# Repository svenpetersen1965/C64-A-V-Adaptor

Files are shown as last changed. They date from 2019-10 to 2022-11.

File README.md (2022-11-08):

# C64-A-V-Adaptor
An A/V-adaptor board for the C64
This board is intended to connect to the Commodore C64 and use standard cables (audio, composite with RCA connector and/or s-video with a mini-DIN cable).

It also provides a 330Ohm resistor, which attenuates the s-video chroma line. This resistor can be bridged with a jumper. 

Also an optional stereo output on pin 7 of the a/v jack (stereo sid, FPGA SID etc.) can be connected to the right audio channel. By default, this channel is also connected to the (mono) audio output.

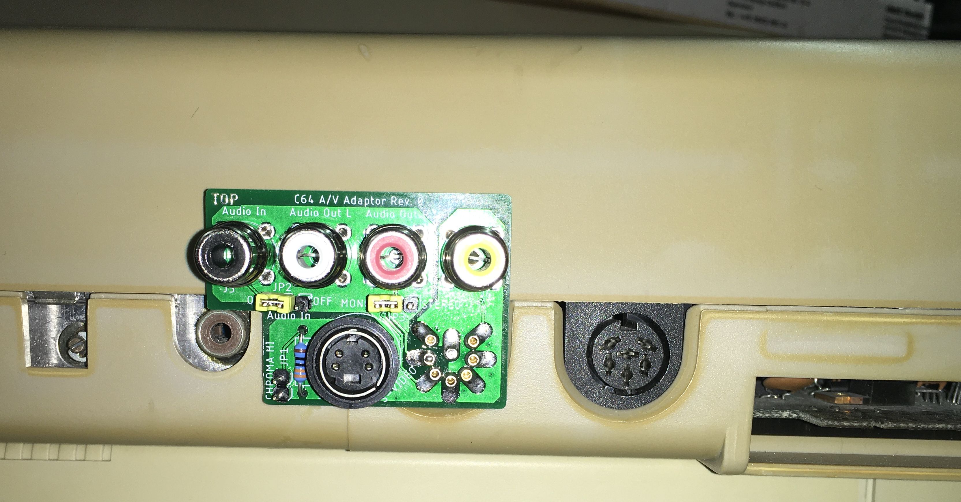
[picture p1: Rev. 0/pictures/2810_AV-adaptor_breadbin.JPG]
C64 A/V-Adaptor


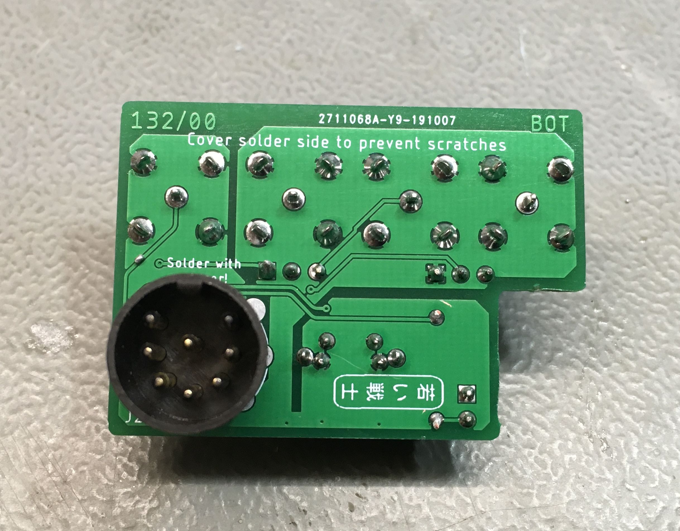
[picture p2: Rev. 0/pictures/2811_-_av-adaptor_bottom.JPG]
C64 A/V-Adaptor (bottom)


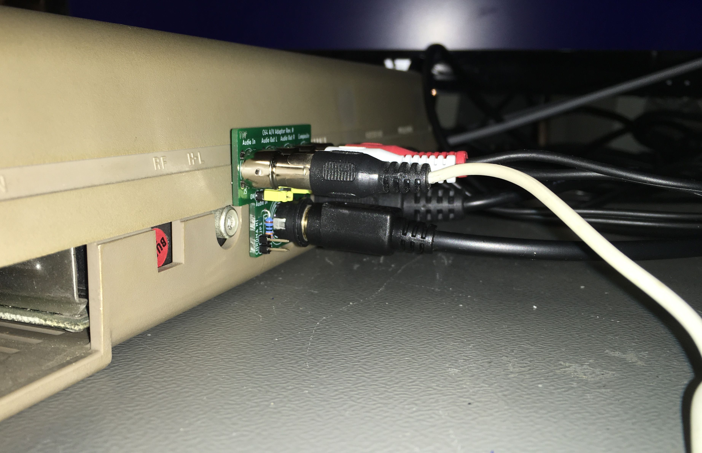
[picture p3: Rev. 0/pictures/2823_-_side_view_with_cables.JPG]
C64 A/V-Adaptor (side view with cables)


There is another source of the Lumberg DIN connector found for north America: https://www.alliedelec.com/product/lumberg/sv-80/70151558/ 

# Case

I have added a 3D printable case for this adaptor.

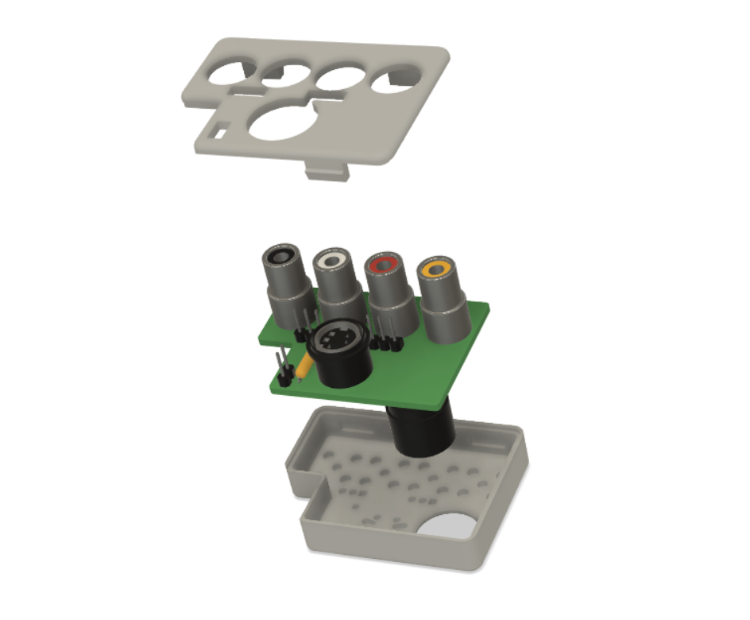
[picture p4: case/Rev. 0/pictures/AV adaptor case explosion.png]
C64 A/V-Adaptor Case


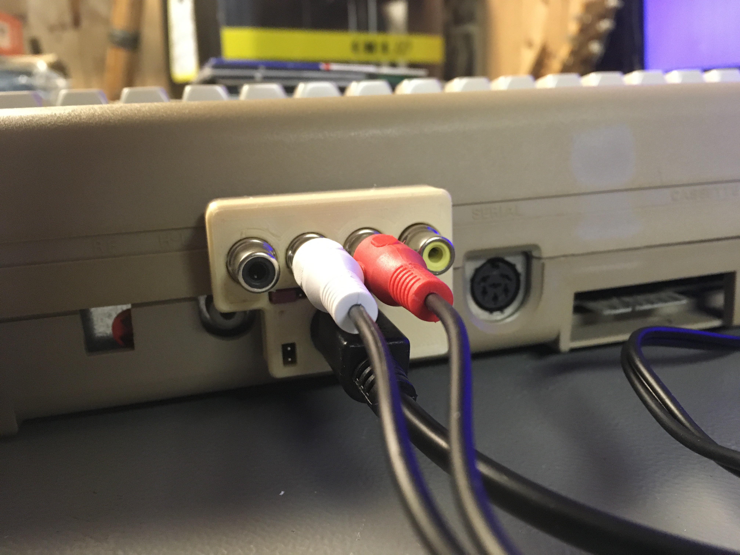
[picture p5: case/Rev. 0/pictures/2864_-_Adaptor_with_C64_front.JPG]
C64 A/V-Adaptor Case


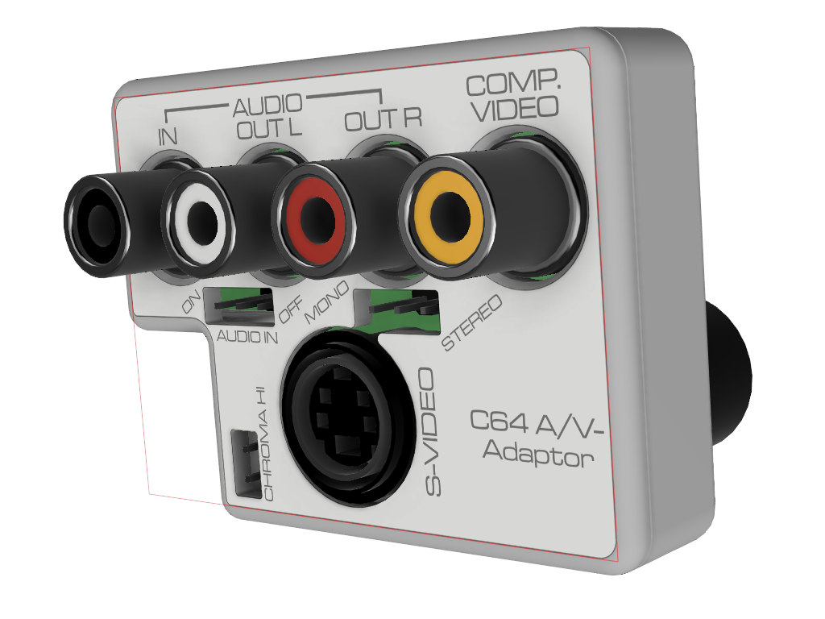
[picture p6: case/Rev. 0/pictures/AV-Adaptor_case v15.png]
C64 A/V-Adaptor Case


# Revision 1
Rev. 1 is exactly the same as Rev. 0, except the spacer, that had to be cut off manually was removed to myke this board a little more mass production friendly. All masures and positions stayed the same. The BOM has not been changed, either (except the PCB Rev. No.).

# Revision 2
In Rev. 2, the obsolete Lumberg BTOR1 RCA jacks are replaced with a model from CUI Inc. Also, there is an alternative from Keystone. Check ou the BOM.

# Prices

I have added a price calculation with prices of May 2020. The  prices per item were retrieved from reichelt.de. They might differ from distributor to distributor (the Lumberg connectors are more expensive in North America) and they don't include any shipping fees.

A standard A/V Adaptor is worth 12,75€ (May 2020) plus the 3D printed case and label.

In September 2022, a new price had to be calculated. The BOM Value is now (Sepüt. 2nd, 2022) 16.63€. 

# VIC-20 & C128

This AV-Adaptor is blocking the Expansion Port of the VIC-20 (the 5 pin version) and the IEC bus of the C128! There are dedicated versions for each.

* <a href="https://github.com/svenpetersen1965/C128-A-V-Adapter">C128 A/V-Adapter</a>
* <a href="https://github.com/svenpetersen1965/VIC-20_AV-Adapter">VIC-20 A/V-Adapter</a>

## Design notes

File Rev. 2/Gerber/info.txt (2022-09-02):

      
       Board: C64_AV-Adaptor
       Rev.:  2
  
       Files:
       ======
  
       All Gerber files are generated in extended gerber format (RS274X)
       *.TOP        : Film top copper
       *.BOT        :  -"- bottom copper
       *.STC        :  -"- top soldermask 
       *.STS        :  -"- bottom soldermask
       *.PLC        :  -"- silk screen top
       *.PLS        :  -"- silk screen bottom
       *.DK         : Drills plated Through (Excellon)
       *.NDK        : Drills not plated Through (Excellon)
       *.OUT        : Board outline

       Board Size:
       ===========
       Length     :   48.0 mm
       Width      :   34.0 mm
       Thickness  :   1.6 mm
       Material   :   FR 4
       Copper     :   35 um
       Surface    :   HASL
       
       Remarks:
       ========
       Width >= 8mil
       Distance >= 6mil
       Drill >= 0.6mm

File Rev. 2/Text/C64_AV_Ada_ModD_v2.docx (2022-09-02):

C64 A/V-Adaptor Rev. 2

Module Description

# Introduction

The A/V-Adaptor allows to connect standard S-Video and Audio or Composite-Video cables to the A/V-Jack of the Commodore C64.

A 330Ω resistor to attenuate the Chroma signal for S-Video is installed, but it can be deactivated by setting a jumper (JP2). This attenuation is required, since the chroma signal has a level, which is too high for standard S-Video.

Further, the audio input can be connected to GND, in case it is not in use to reduce the noise introduction.

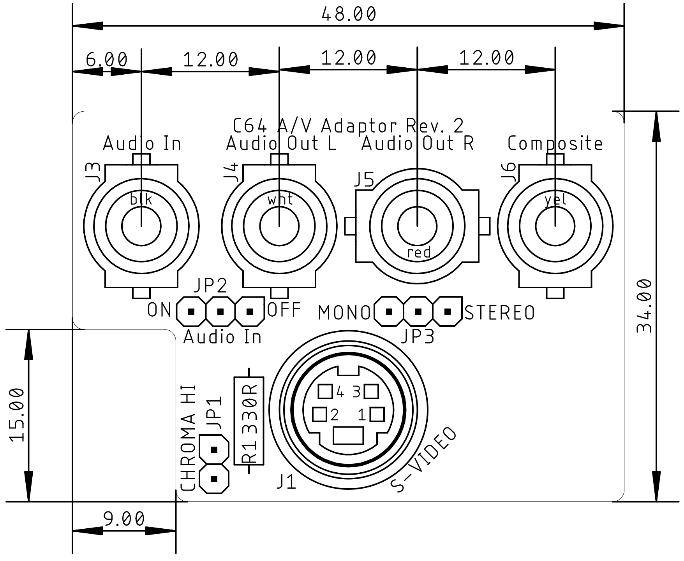
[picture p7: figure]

Figure 1: Component side of the A/V-Adaptor

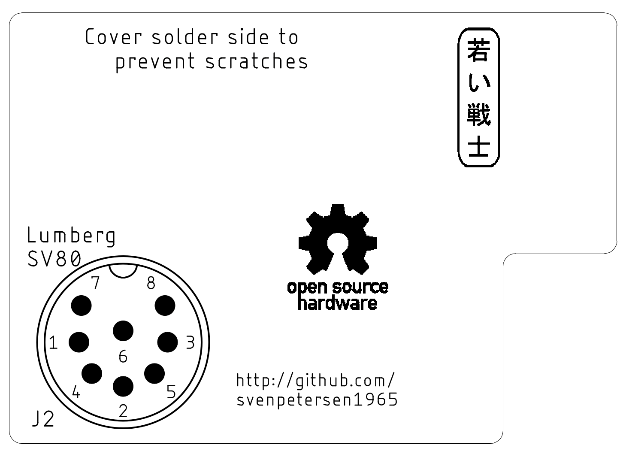
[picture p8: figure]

Figure 2: Solder side of the A/V-Adaptor

The two audio output jacks can be connected by a jumper. Alternatively, the stereo sound output (A/V-Jack, pin 7, in case a 2nd SID is installed inside the C64) can be connected to the right channel of the audio output. The first SID output is connected to the left channel of the audio output.

Since the DIN jack for the C64 (J2) has to be installed with a distance, a soldering aid (spacer) is provided with the PCB. It should be clipped off and put between the PCB and J2 while soldering to keep the right distance and angle. After assembly, it can be discarded.

# The C64 A/V-Adapter and the Ultimate 64

The Ultimate 64 does not provide an audio input and the second stereo output is located on pin 5 of the A/V jack. This is the same like the audio input of the C64.

1. The 2nd (right) audio output is connected to the black RCA jack
2. The jumper JP2 must not be set to off
3. The jumper JP3 can be set either way (on or off)

# Connectors

## A/V-Plug – J2

The A/V-Plug for the C64 is the inner part of a Lumberg 033099 SV 80 DIN-Plug (8 pins, horse shoe = 262°). It provides a round plastic shell of the DIN-connector and long enough pins, so the adaptor can sit firmly in the A/V jack. The inner part of a cheaper (standard) connector cannot be used, since it does not sit firm enough.

Pin | Signal
1 | Luminance
2 | GND
3 | Audio Out (mono/left)
4 | Composite Video
5 | Audio In
6 | Chrominance
7 | Audio Out (right – if provided)
8 | -

## S-Video Jack – J1

A vertical PCB mount Mini-DIN jack (4 circuits)

Pin | Signal
1 | GND (Luminance)
2 | GND (Chrominance)
3 | Luminance
4 | Chrominance

## RCA-Jacks – J3, J4, J5 & J6

Connector | Signal
J4 | Audio Out (mono/left)
J5 | Audio Out (mono/right)
J3 | Audio In
J6 | Composite Video

# Jumpers

## Chrominance attenuation – JP1

The chrominance signal has a too high level for the standard S-Video chroma signal. The jumper bridges the 330Ω resistor (R1) to switch off this attenuation.

Status | Configuration
open | Attenuation active
set | Attenuation inactive/off

## Audio Input Off – JP2

To reduce the noise introduction to the Audio Input, this can be grounded.

Status | Configuration
ON | SID Audio In connected to J5
OFF | SID Audio In connected to GND

## Mono/Stereo – JP3

The standard audio output of the SID is one channel (mono). In cases a 2nd SID is installed, the 2nd audio output is (usually) connected to Pin 7 of the Audio/Video jack of the C64. JP3 connected the right channel of the audio output (J4) to either J2, Pin 3 or Pin 7.

Status | Configuration
MONO | J4 connected to J2, Pin 3
STEREO | J4 connected to J2, Pin 7

# Assembly

Install the DIN plug (J2) on the solder side (bottom) first. Put the PCB on a suitable surface, the solder side up. Insert the DIN-plug, make sure, it is vertical and solder one pin first (from the solder side, which is pointing up, refer to Figure 3). Check again that the plug is straight, correct if required and finally solder all other pins.

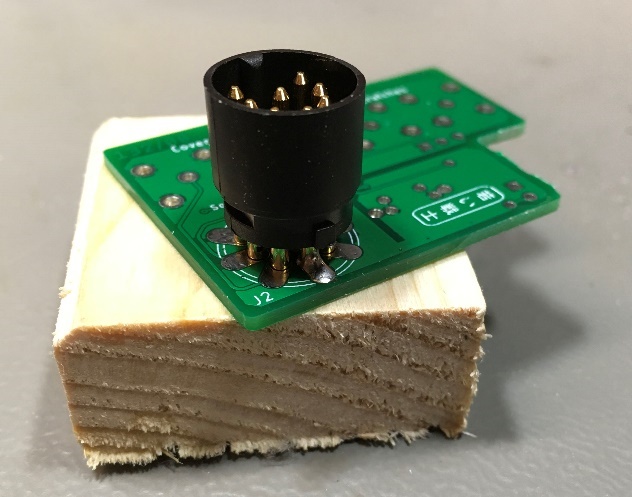
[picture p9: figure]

Figure 3: Soldering the DIN-plug J2

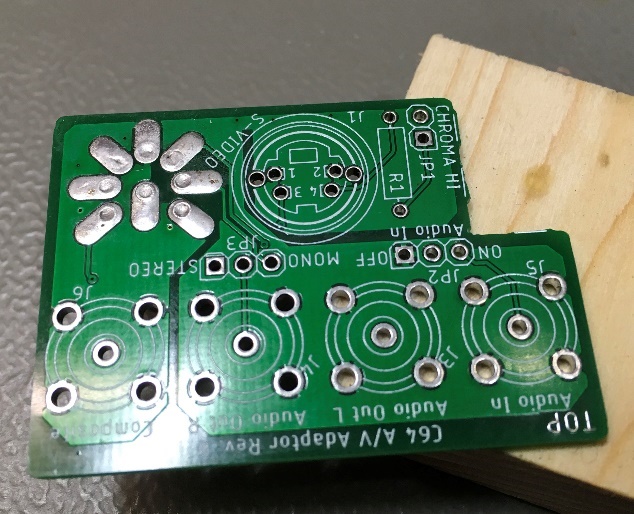
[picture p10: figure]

Figure 4: DIN-plug seen from the component side ("TOP")

Install and solder all other components from the component side. Watch the angle of the components, solder them from the solder side. Clip excess pin length.

In case no enclosure is used, cover the solder side (except J2) with duct tape to prevent scratching the case of the C64.

# Versions for the ASSY 326298 (5-pin)

ASSY 326298 was the first model of the C64, which was built in 1982. It did not have all S-Video signals. Chroma is missing. Thus, a 5-pin DIN plug is required for J2. The S-Video jack (J1) is not required.

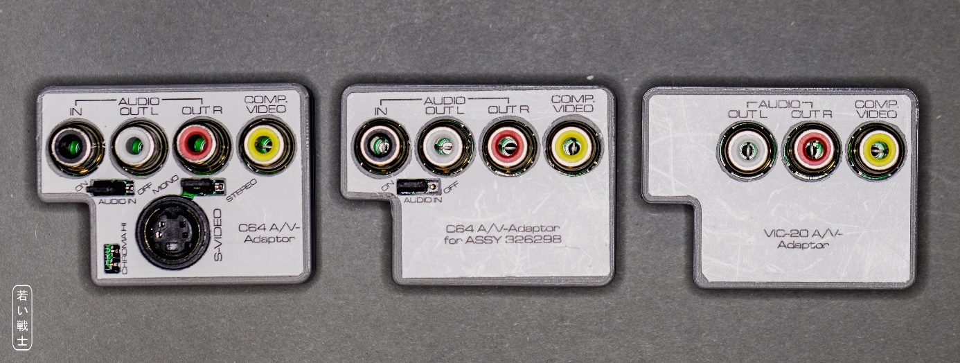
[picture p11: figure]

Figure 5: The three models of the A/V-Adaptor

The shown VIC-20 version is blocking the expansion port and it not recommended.

Component | C64 regular | C64 ASSY326298
J2 (DIN) | SV 80 (8 pin) | SV 50 (5 pin)
J1 (S-Video) | populate | do not populate
J5 (RCA: Audio in) | populate | populate
JP1 (Chroma 330Ω) | populate | do not populate
JP2 (Audio In) | populate | populate
JP3 (mono/stereo) | populate | hardwire to mono
R1 (330Ω) | populate | do not populate

SV 80 and SV 50 are Lumberg components.

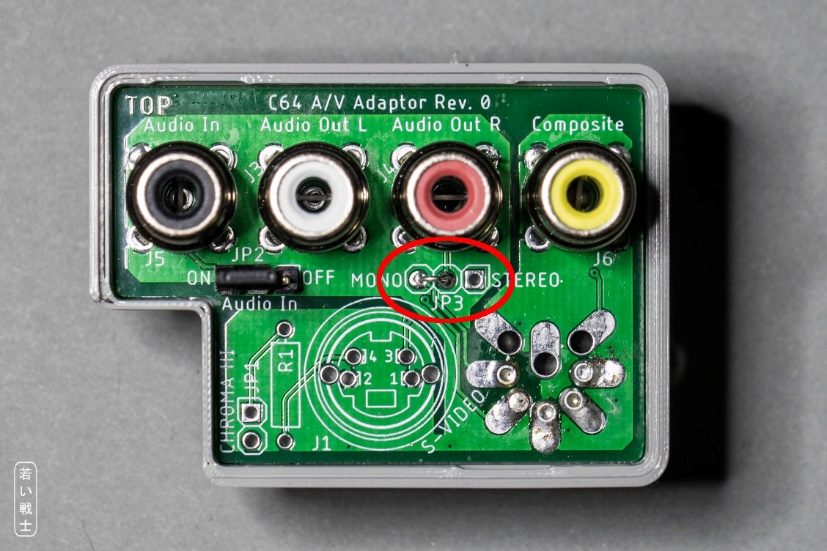
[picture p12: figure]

Figure 6: JP3 hardwired to mono

JP3 can be hardwired using a short piece of wire.

# 3D-printed Case

The bottom shell recessed for the solder pads to provide a very short distance between the case of the C64 and the circuit board of this adapter. The solder pads have changed in Rev. 2, so it also requires a different bottom shell (case for PCB Rev. 2).

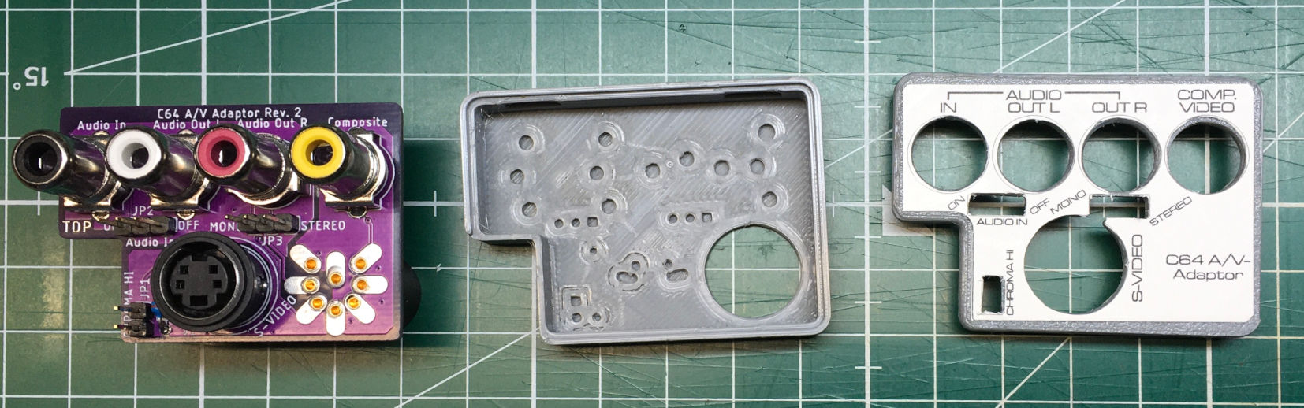
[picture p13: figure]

Figure 7: A/V-adapter Rev. 2 and 3D-printed case

# Revision History

## Rev. 0 → Rev. 1

Spacer was removed from the design.

## Rev. 1 → Rev. 2

The obsolete Lumberg BTOR1 RCA connectors were replaced with CUI Inc. RCJ-02X type connectors. For the Keystone replacement part, please refer to the BOM.

C64_AV_Ada_ModD_v2.docx 02.09.2022 16:25 Drafted by Sven Petersen Page 2 of 2 Doc.-No.: 132-6-01-02

C64_AV_Ada_ModD_v2.docx 02.09.2022 16:25 Drafted by Sven Petersen Page 1 of 1 Doc.-No.: 000-6-00-00

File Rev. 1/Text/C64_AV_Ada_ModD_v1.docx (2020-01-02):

C64 A/V-Adaptor Rev. 1

Module Description

# Introduction

The A/V-Adaptor allows to connect standard S-Video and Audio or Composite-Video cables to the A/V-Jack of the Commodore C64.

A 330Ω resistor to attenuate the Chroma signal for S-Video is installed, but it can be deactivated by setting a jumper (JP2). This attenuation is required, since the chroma signal has a level, which is too high for standard S-Video.

Further, the audio input can be connected to GND, in case it is not in use to reduce the noise introduction.

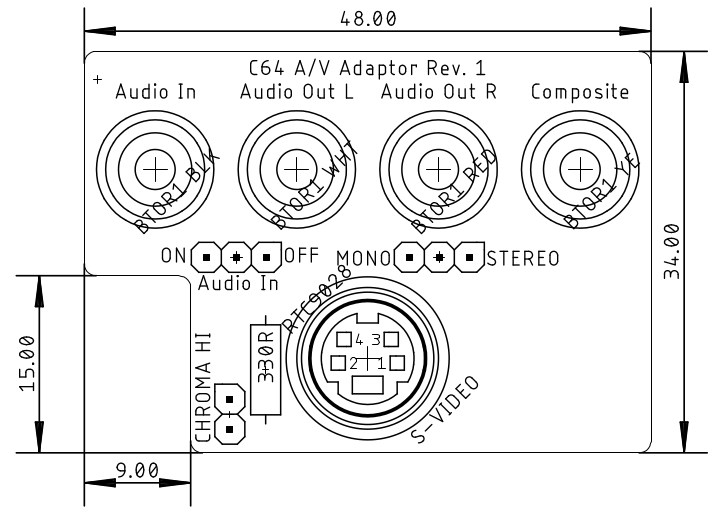
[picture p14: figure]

Figure 1: Component side of the A/V-Adaptor

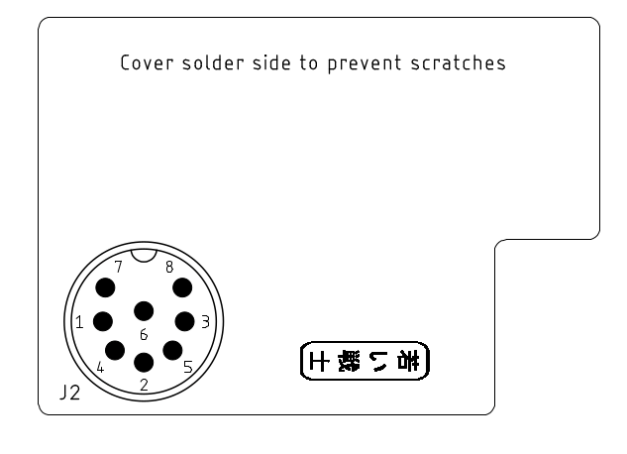
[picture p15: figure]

Figure 2: Solder side of the A/V-Adaptor

The two audio output jacks can be connected by a jumper. Alternatively, the stereo sound output (A/V-Jack, pin 7, in case a 2nd SID is installed inside the C64) can be connected to the right channel of the audio output. The first SID output is connected to the left channel of the audio output.

Since the DIN jack for the C64 (J2) has to be installed with a distance, a soldering aid (spacer) is provided with the PCB. It should be clipped off and put between the PCB and J2 while soldering to keep the right distance and angle. After assembly, it can be discarded.

# Connectors

## A/V-Plug – J2

The A/V-Plug for the C64 is the inner part of a Lumberg 033099 SV 80 DIN-Plug (8 pins, horse shoe = 262°). It provides a round plastic shell of the DIN-connector and long enough pins, so the adaptor can sit firmly in the A/V jack. The inner part of a cheaper (standard) connector cannot be used, since it does not sit firm enough.

Pin | Signal
1 | Luminance
2 | GND
3 | Audio Out (mono/left)
4 | Composite Video
5 | Audio In
6 | Chrominance
7 | Audio Out (right – if provided)
8 | -

## S-Video Jack – J1

A vertical PCB mount Mini-DIN jack (4 circuits)

Pin | Signal
1 | GND (Luminance)
2 | GND (Chrominance)
3 | Luminance
4 | Chrominance

## RCA-Jacks – J3, J4, J5 & J6

Connector | Signal
J3 | Audio Out (mono/left)
J4 | Audio Out (mono/right)
J5 | Audio In
J6 | Composite Video

# Jumpers

## Chrominance attenuation – JP1

The chrominance signal has a too high level for the standard S-Video chroma signal. The jumper bridges the 330Ω resistor (R1) to switch off this attenuation.

Status | Configuration
open | Attenuation active
set | Attenuation inactive/off

## Audio Input Off – JP2

To reduce the noise introduction to the Audio Input, this can be grounded.

Status | Configuration
ON | SID Audio In connected to J5
OFF | SID Audio In connected to GND

## Mono/Stereo – JP3

The standard audio output of the SID is one channel (mono). In cases a 2nd SID is installed, the 2nd audio output is (usually) connected to Pin 7 of the Audio/Video jack of the C64. JP3 connected the right channel of the audio output (J4) to either J2, Pin 3 or Pin 7.

Status | Configuration
MONO | J4 connected to J2, Pin 3
STEREO | J4 connected to J2, Pin 7

# Assembly

Install the DIN plug (J2) on the solder side (bottom) first. Put the PCB on a suitable surface, the solder side up. Insert the DIN-plug, make sure, it is vertical and solder one pin first (from the solder side, which is pointing up, refer to Figure 3). Check again that the plug is straight, correct if required and finally solder all other pins.


Figure 3: Soldering the DIN-plug J2


Figure 4: DIN-plug seen from the component side ("TOP")

Install and solder all other components from the component side. Watch the angle of the components, solder them from the solder side. Clip excess pin length.

In case no enclosure is used, cover the solder side (except J2) with duct tape to prevent scratching the case of the C64.

# Versions for the ASSY 326298 (5-pin) and the VIC-20

ASSY 326298 was the first model of the C64, which was built in 1982. It did not have all S-Video signals. Chroma is missing. Thus, a 5-pin DIN plug is required for J2. The S-Video jack (J1) is not required.


Figure 5: The three models of the A/V-Adaptor

The VIC-20 also requires a 5-pin DIN plug but no Audio-in RCA jack.

Component | C64 regular | C64 ASSY326298 | VIC-20
J2 (DIN) | SV 80 (8 pin) | SV 50 (5 pin) | SV 50 (5 pin)
J1 (S-Video) | populate | do not populate | do not populate
J5 (RCA: Audio in) | populate | populate | do not populate
JP1 (Chroma 330Ω) | populate | do not populate | do not populate
JP2 (Audio In) | populate | populate | do not populate
JP3 (mono/stereo) | populate | hardwire to mono | hardwire to mono
R1 (330Ω) | populate | do not populate | do not populate

SV 80 and SV 50 are Lumberg components.


Figure 6: JP3 hardwired to mono

JP3 can be hardwired using a short piece of wire.

# Revision History

## Rev. 0 → Rev. 1

Spacer was removed from the design.

C64_AV_Ada_ModD_v1.docx 02.01.2020 19:51 Drafted by Sven Petersen Page 2 of 2 Doc.-No.: 132-6-01-01

C64_AV_Ada_ModD_v1.docx 02.01.2020 19:51 Drafted by Sven Petersen Page 1 of 1 Doc.-No.: 000-6-00-00

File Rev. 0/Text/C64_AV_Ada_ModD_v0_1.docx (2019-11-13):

C64 A/V-Adaptor Rev. 0

Module Description v0.1

# Introduction

The A/V-Adaptor allows to connect standard S-Video and Audio or Composite-Video cables to the A/V-Jack of the Commodore C64.

A 330Ω resistor to attenuate the Chroma signal for S-Video is installed, but it can be deactivated by setting a jumper (JP2). This attenuation is required, since the chroma signal has a level, which is too high for standard S-Video.

Further, the audio input can be connected to GND, in case it is not in use to reduce the noise introduction.

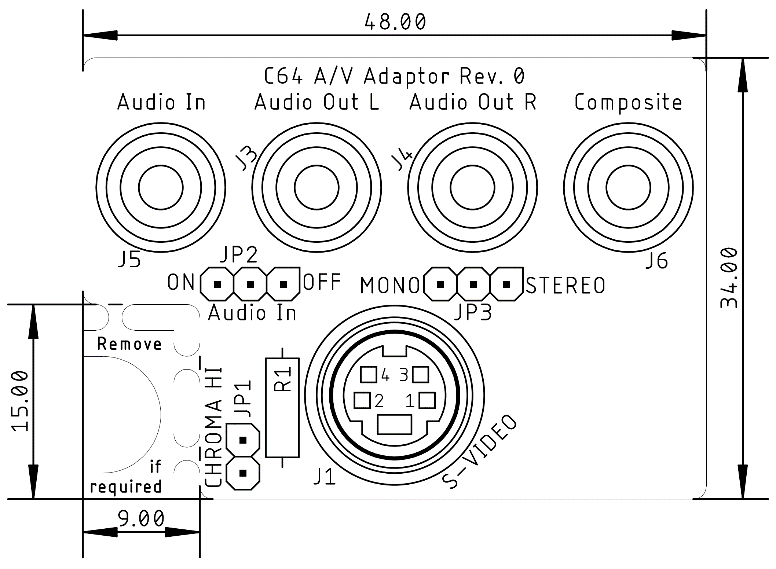
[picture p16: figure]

Figure 1: Component side of the A/V-Adaptor

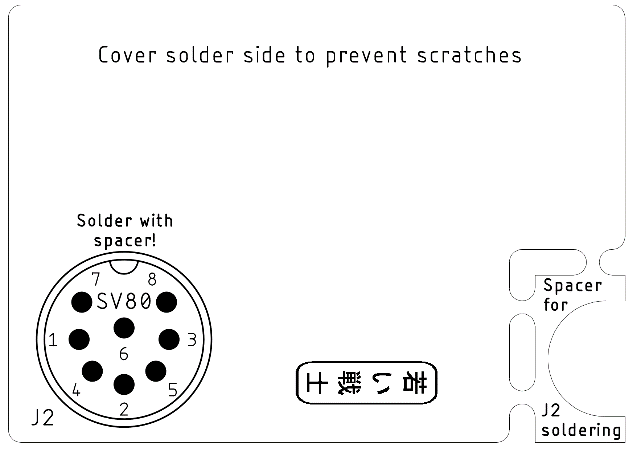
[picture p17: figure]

Figure 2: Solder side of the A/V-Adaptor

The two audio output jacks can be connected by a jumper. Alternatively, the stereo sound output (A/V-Jack, pin 7, in case a 2nd SID is installed inside the C64) can be connected to the right channel of the audio output. The first SID output is connected to the left channel of the audio output.

Since the DIN jack for the C64 (J2) has to be installed with a distance, a soldering aid (spacer) is provided with the PCB. It should be clipped off and put between the PCB and J2 while soldering to keep the right distance and angle. After assembly, it can be discarded.

# Connectors

## A/V-Plug – J2

The A/V-Plug for the C64 is the inner part of a Lumberg 033099 SV 80 DIN-Plug (8 pins, horse shoe = 262°). It provides a round plastic shell of the DIN-connector and long enough pins, so the adaptor can sit firmly in the A/V jack. The inner part of a cheaper (standard) connector cannot be used, since it does not sit firm enough.

Pin | Signal
1 | Luminance
2 | GND
3 | Audio Out (mono/left)
4 | Composite Video
5 | Audio In
6 | Chrominance
7 | Audio Out (right – if provided)
8 | -

## S-Video Jack – J1

A vertical PCB mount Mini-DIN jack (4 circuits)

Pin | Signal
1 | GND (Luminance)
2 | GND (Chrominance)
3 | Luminance
4 | Chrominance

## RCA-Jacks – J3, J4, J5 & J6

Connector | Signal
J3 | Audio Out (mono/left)
J4 | Audio Out (mono/right)
J5 | Audio In
J6 | Composite Video

# Jumpers

## Chrominance attenuation – JP1

The chrominance signal has a too high level for the standard S-Video chroma signal. The jumper bridges the 330Ω resistor (R1) to switch off this attenuation.

Status | Configuration
open | Attenuation active
set | Attenuation inactive/off

## Audio Input Off – JP2

To reduce the noise introduction to the Audio Input, this can be grounded.

Status | Configuration
ON | SID Audio In connected to J5
OFF | SID Audio In connected to GND

## Mono/Stereo – JP3

The standard audio output of the SID is one channel (mono). In cases a 2nd SID is installed, the 2nd audio output is (usually) connected to Pin 7 of the Audio/Video jack of the C64. JP3 connected the right channel of the audio output (J4) to either J2, Pin 3 or Pin 7.

Status | Configuration
MONO | J4 connected to J2, Pin 3
STEREO | J4 connected to J2, Pin 7

# Assembly

Install the A/V plug (J2) on the solder side (bottom) by putting the spacer, which is provided as a part of the PCB, between the PCB and the plug. Make sure, it is parallel to the board. Solder it from the component side. A distance of at least 1.6mm is required (the thickness of the spacer is 1.6mm), 2mm is even better.

Install and solder all other components from the component side. Watch the angle of the components, solder them from the solder side. Clip excess pin length.

Cover the solder side (except J2) with duct tape to prevent scratching the case of the C64.

A 3D-printed case is the better solution here.

# Versions for the ASSY 326298 (5-pin) and the VIC-20

ASSY 326298 was the first model of the C64, which was built in 1982. It did not have all S-Video signals. Chroma is missing. Thus, a 5-pin DIN plug is required for J2. The S-Video jack (J1) is not required.


Figure 3: The three models of the A/V-Adaptor

The VIC-20 also requires a 5-pin DIN plug but no Audio-in RCA jack.

Component | C64 regular | C64 ASSY326298 | VIC-20
J2 (DIN) | SV 80 (8 pin) | SV 50 (5 pin) | SV 50 (5 pin)
J1 (S-Video) | populate | do not populate | do not populate
J5 (RCA: Audio in) | populate | populate | do not populate
JP1 (Chroma 330Ω) | populate | do not populate | do not populate
JP2 (Audio In) | populate | populate | do not populate
JP3 (mono/stereo) | populate | hardwire to mono | hardwire to mono
R1 (330Ω) | populate | do not populate | do not populate

SV 80 and SV 50 are Lumberg components.


Figure 4: JP3 hardwired to mono

JP3 can be hardwired using a short piece of wire.

C64_AV_Ada_ModD_v0_1.docx 13.11.2019 14:52 Drafted by Sven Petersen Page 2 of 2 Doc.-No.: 132-6-01-00.1

C64_AV_Ada_ModD_v0_1.docx 13.11.2019 14:52 Drafted by Sven Petersen Page 1 of 1 Doc.-No.: 000-6-00-00

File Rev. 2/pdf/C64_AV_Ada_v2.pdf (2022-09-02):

# Project Documentation

## C64 A/V-Adaptor

## Project number: 132

## Revision: 2

## Date: 22.06.2022

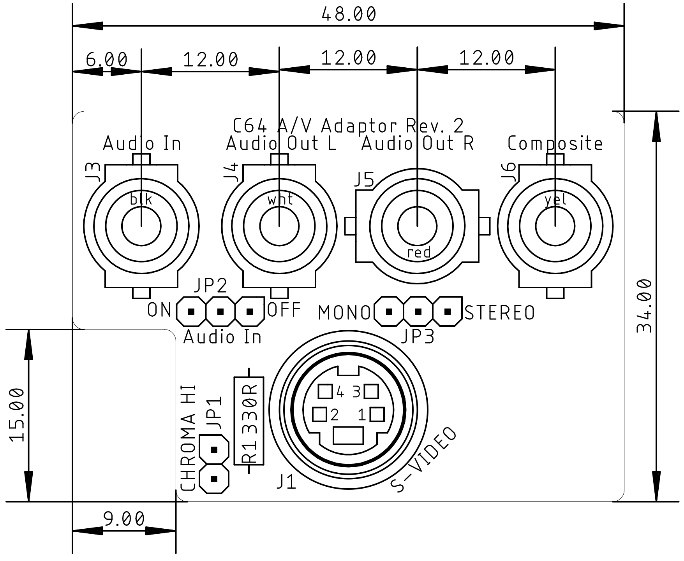
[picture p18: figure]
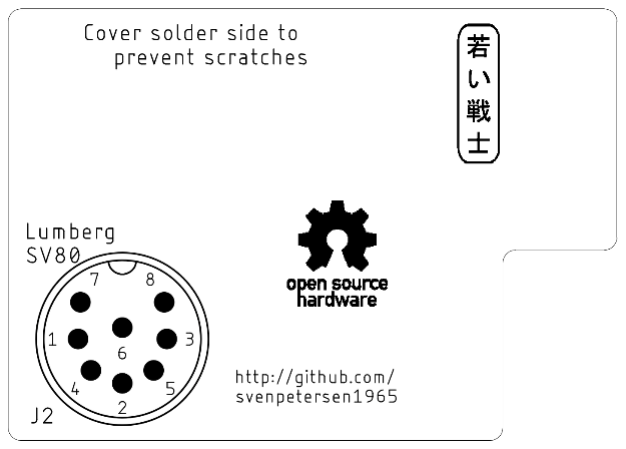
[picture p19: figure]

C64_AV_Ada_ModD_v2.docx | | 02.09.2022 16:25
Drafted by Sven Petersen | Page 1 of 5 | Doc.-No.: 132-6-01-02

### C64 A/V-Adaptor Rev. 2

### Module Description

## Introduction

The A/V-Adaptor allows to connect standard S-Video and Audio or Composite-Video cables to the A/V-Jack of the Commodore C64.

A 330Ω resistor to attenuate the Chroma signal for S-Video is installed, but it can be deactivated by setting a jumper (JP2). This attenuation is required, since the chroma signal has a level, which is too high for standard S-Video.

Further, the audio input can be connected to GND, in case it is not in use to reduce the noise introduction.

Figure 1: Component side of the A/V-Adaptor

Figure 2: Solder side of the A/V-Adaptor

The two audio output jacks can be connected by a jumper. Alternatively, the stereo sound output (A/V-Jack, pin 7, in case a 2nd SID is installed inside the C64) can be connected to the right channel of the audio output. The first SID output is connected to the left channel of the audio output.

C64_AV_Ada_ModD_v2.docx | | 02.09.2022 16:25
Drafted by Sven Petersen | Page 2 of 5 | Doc.-No.: 132-6-01-02

Since the DIN jack for the C64 (J2) has to be installed with a distance, a soldering aid (spacer) is provided with the PCB. It should be clipped off and put between the PCB and J2 while soldering to keep the right distance and angle. After assembly, it can be discarded.

## The C64 A/V-Adapter and the Ultimate 64

The Ultimate 64 does not provide an audio input and the second stereo output is located on pin 5 of the A/V jack. This is the same like the audio input of the C64.

### 1. The 2nd (right) audio output is connected to the black RCA jack 2. The jumper JP2 must not be set to off 3. The jumper JP3 can be set either way (on or off)

## Connectors

### A/V-Plug – J2

The A/V-Plug for the C64 is the inner part of a Lumberg 033099 SV 80 DIN-Plug (8 pins, horse shoe = 262°). It provides a round plastic shell of the DIN-connector and long enough pins, so the adaptor can sit firmly in the A/V jack. The inner part of a cheaper (standard) connector cannot be used, since it does not sit firm enough.

Pin Signal
1 Luminance
2 GND
3 Audio Out (mono/left)
4 Composite Video
5 Audio In
6 Chrominance
7 Audio Out (right – if provided) 8 -

### S-Video Jack – J1

A vertical PCB mount Mini-DIN jack (4 circuits)

Pin Signal
1 GND (Luminance)
2 GND (Chrominance)
3 Luminance
4 Chrominance

### RCA-Jacks – J3, J4, J5 & J6

Connector Signal
J4 | Audio Out (mono/left)
J5 | Audio Out (mono/right)
J3 | Audio In
J6 | Composite Video

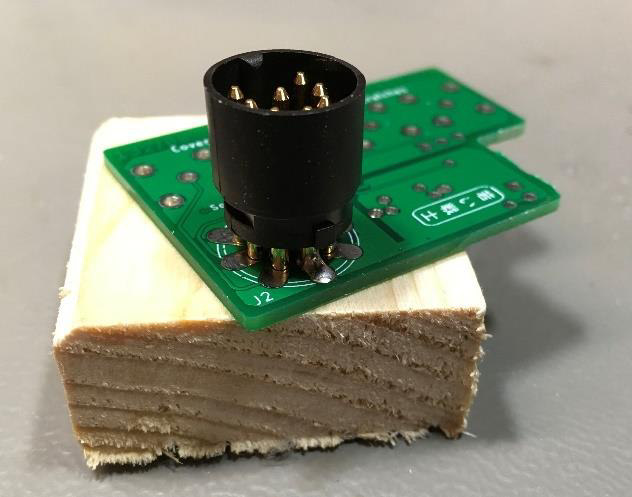
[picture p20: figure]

C64_AV_Ada_ModD_v2.docx | | 02.09.2022 16:25
Drafted by Sven Petersen | Page 3 of 5 | Doc.-No.: 132-6-01-02

## Jumpers

### Chrominance attenuation – JP1

The chrominance signal has a too high level for the standard S-Video chroma signal. The jumper bridges the 330Ω resistor (R1) to switch off this attenuation.

Status Configuration
open | Attenuation active
set | Attenuation inactive/off

### Audio Input Off – JP2

To reduce the noise introduction to the Audio Input, this can be grounded.

Status Configuration
ON | SID Audio In connected to J5
OFF | SID Audio In connected to GND

### Mono/Stereo – JP3

The standard audio output of the SID is one channel (mono). In cases a 2

nd SID is installed, the 2nd audio output is (usually) connected to Pin 7 of the Audio/Video jack of the C64. JP3 connected the right channel of the audio output (J4) to either J2, Pin 3 or Pin 7.

Status | Configuration
MONO | J4 connected to J2, Pin 3
STEREO | J4 connected to J2, Pin 7

## Assembly

Install the DIN plug (J2) on the solder side (bottom) first. Put the PCB on a suitable surface, the solder side up. Insert the DIN-plug, make sure, it is vertical and solder one pin first (from the solder side, which is pointing up, refer to Figure 3). Check again that the plug is straight, correct if required and finally solder all other pins.

Figure 3: Soldering the DIN-plug J2

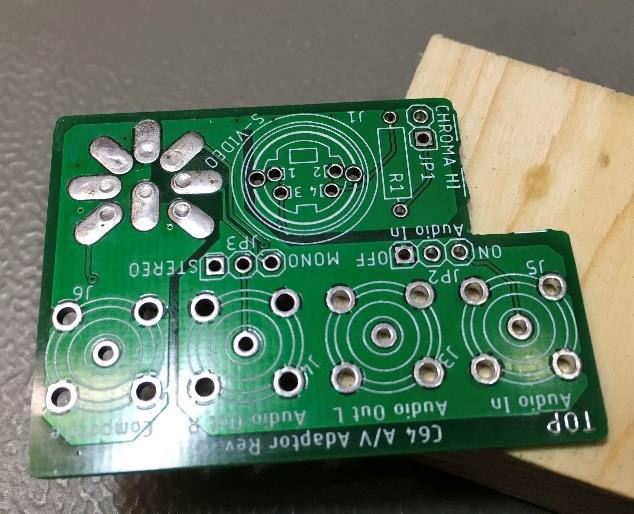
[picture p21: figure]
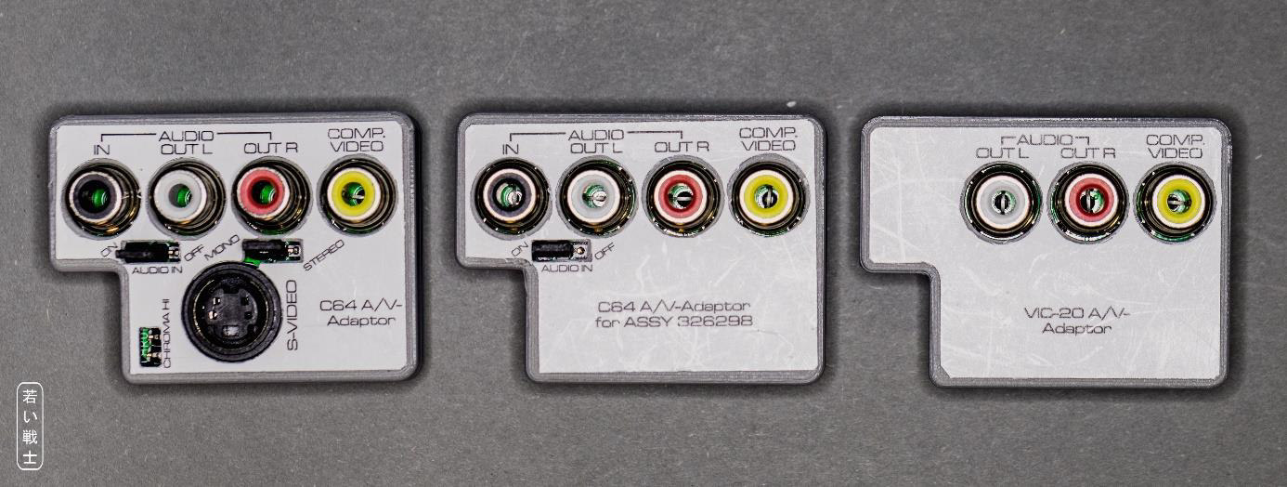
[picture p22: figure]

C64_AV_Ada_ModD_v2.docx | | 02.09.2022 16:25
Drafted by Sven Petersen | Page 4 of 5 | Doc.-No.: 132-6-01-02

Figure 4: DIN-plug seen from the component side ("TOP")

Install and solder all other components from the component side. Watch the angle of the components, solder them from the solder side. Clip excess pin length.

In case no enclosure is used, cover the solder side (except J2) with duct tape to prevent scratching the case of the C64.

## Versions for the ASSY 326298 (5-pin)

ASSY 326298 was the first model of the C64, which was built in 1982. It did not have all S-Video signals. Chroma is missing. Thus, a 5-pin DIN plug is required for J2. The S-Video jack (J1) is not required.

Figure 5: The three models of the A/V-Adaptor

The shown VIC-20 version is blocking the expansion port and it not recommended.

Component | C64 regular | C64 ASSY326298
J2 (DIN) | SV 80 (8 pin) | SV 50 (5 pin)
J1 (S-Video) | populate | do not populate
J5 (RCA: Audio in) | populate | populate
JP1 (Chroma 330Ω) | populate | do not populate
JP2 (Audio In) | populate | populate
JP3 (mono/stereo) | populate | hardwire to mono
R1 (330Ω) | populate | do not populate

SV 80 and SV 50 are Lumberg components.

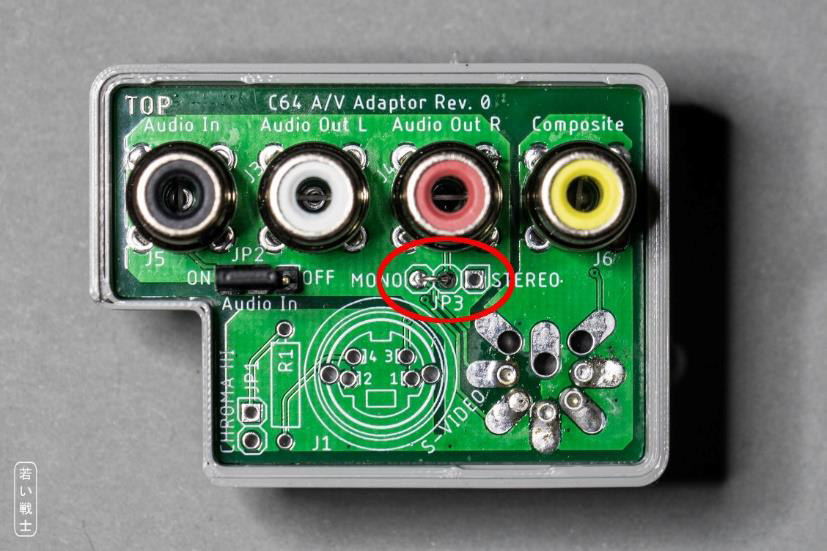
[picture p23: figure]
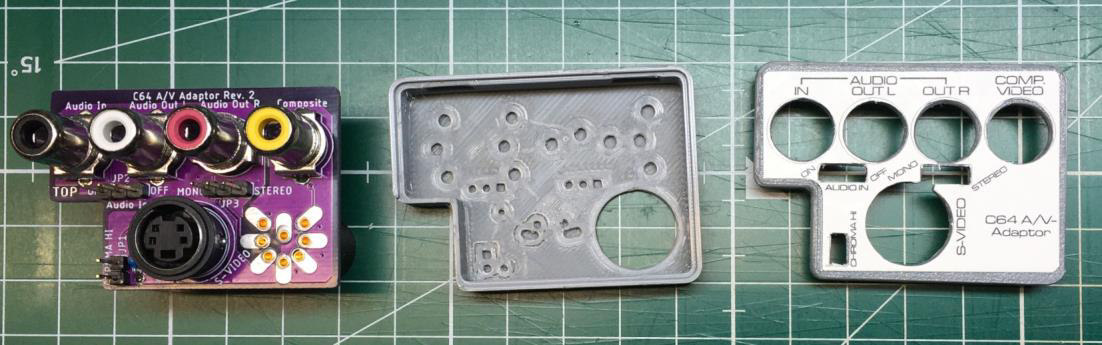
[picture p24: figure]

C64_AV_Ada_ModD_v2.docx | | 02.09.2022 16:25
Drafted by Sven Petersen | Page 5 of 5 | Doc.-No.: 132-6-01-02

Figure 6: JP3 hardwired to mono

JP3 can be hardwired using a short piece of wire.

## 3D-printed Case

The bottom shell recessed for the solder pads to provide a very short distance between the case of the C64 and the circuit board of this adapter. The solder pads have changed in Rev. 2, so it also requires a different bottom shell (case for PCB Rev. 2).

Figure 7: A/V-adapter Rev. 2 and 3D-printed case

## Revision History

### Rev. 0 → Rev. 1

Spacer was removed from the design.

### Rev. 1 → Rev. 2

The obsolete Lumberg BTOR1 RCA connectors were replaced with CUI Inc. RCJ-02X type connectors. For the Keystone replacement part, please refer to the BOM.

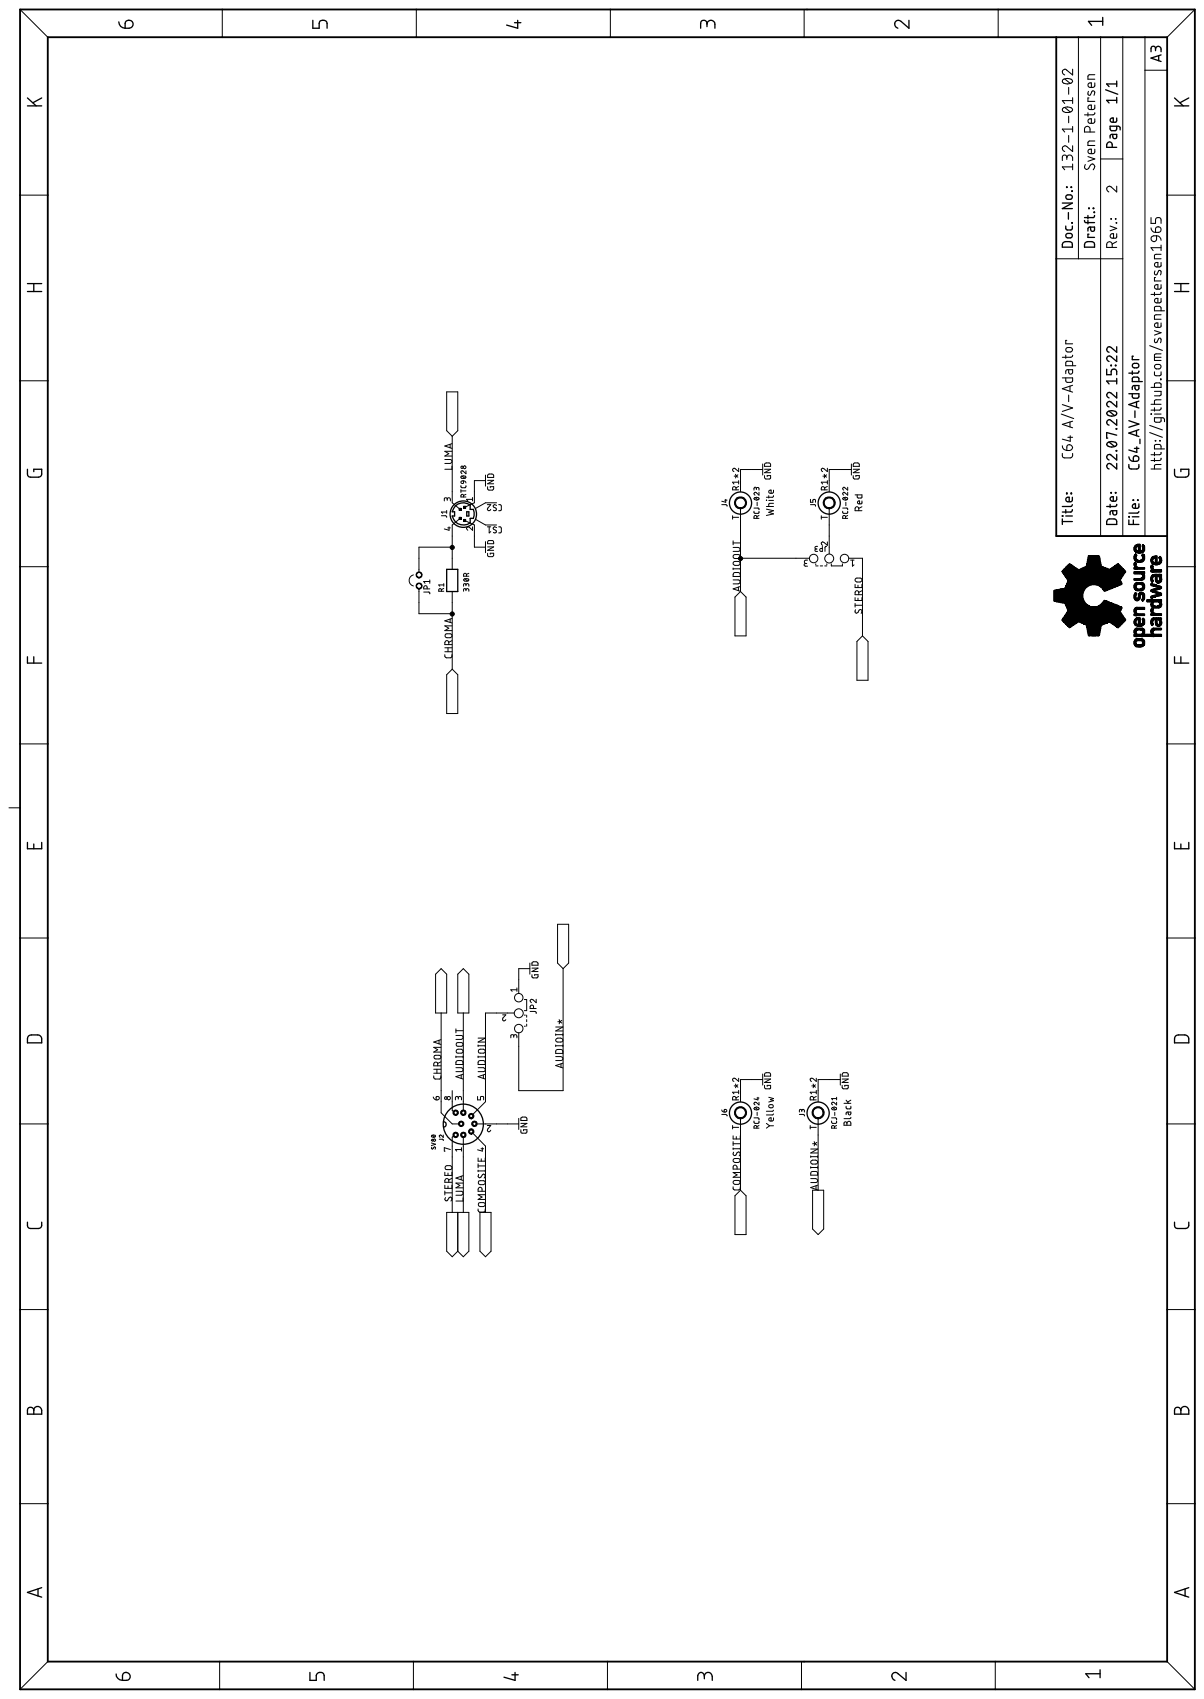
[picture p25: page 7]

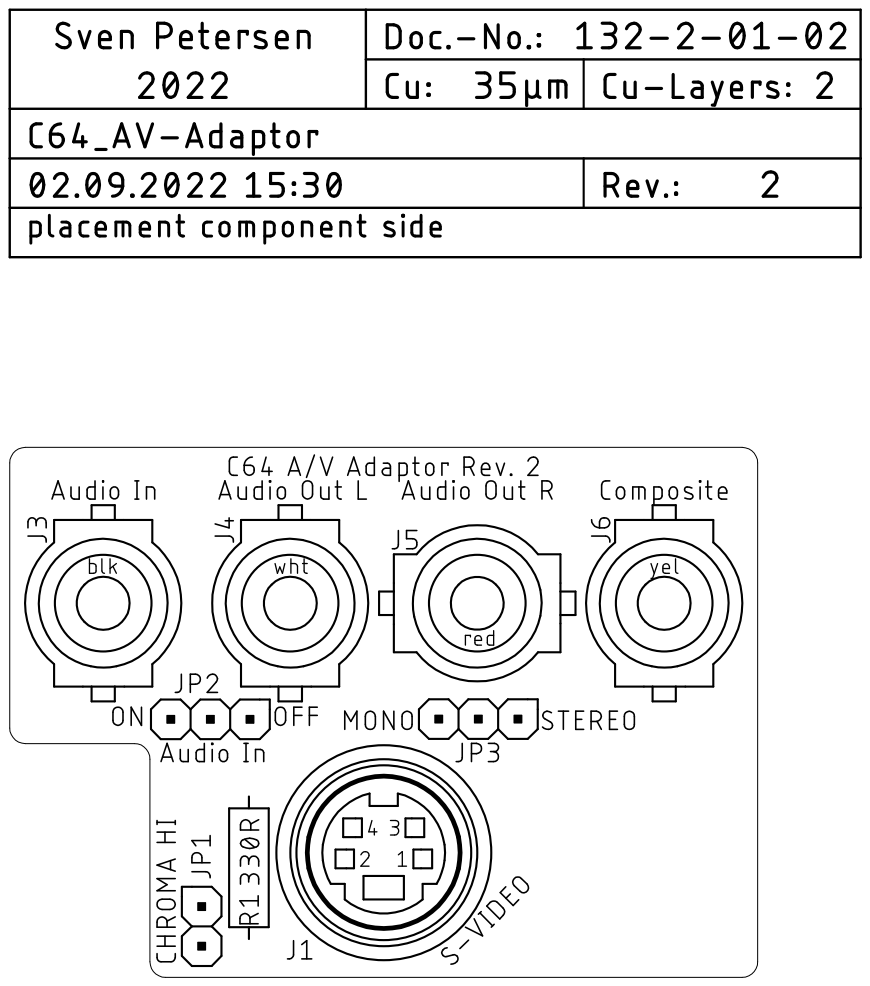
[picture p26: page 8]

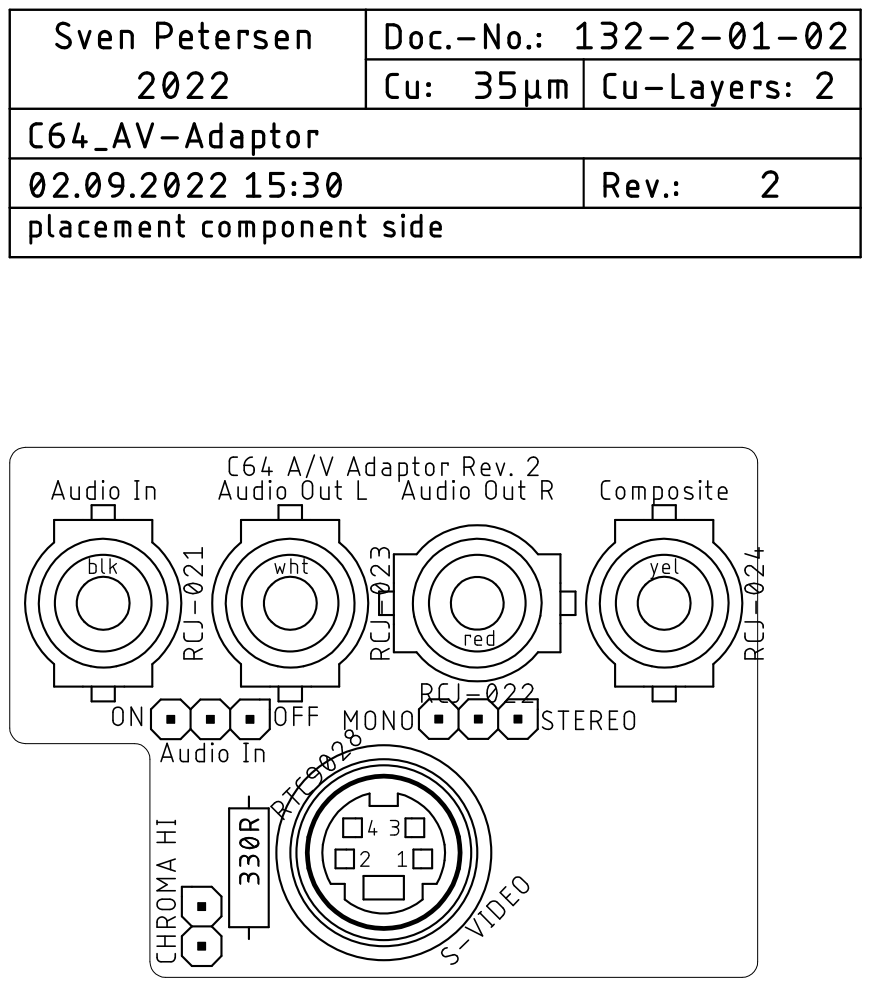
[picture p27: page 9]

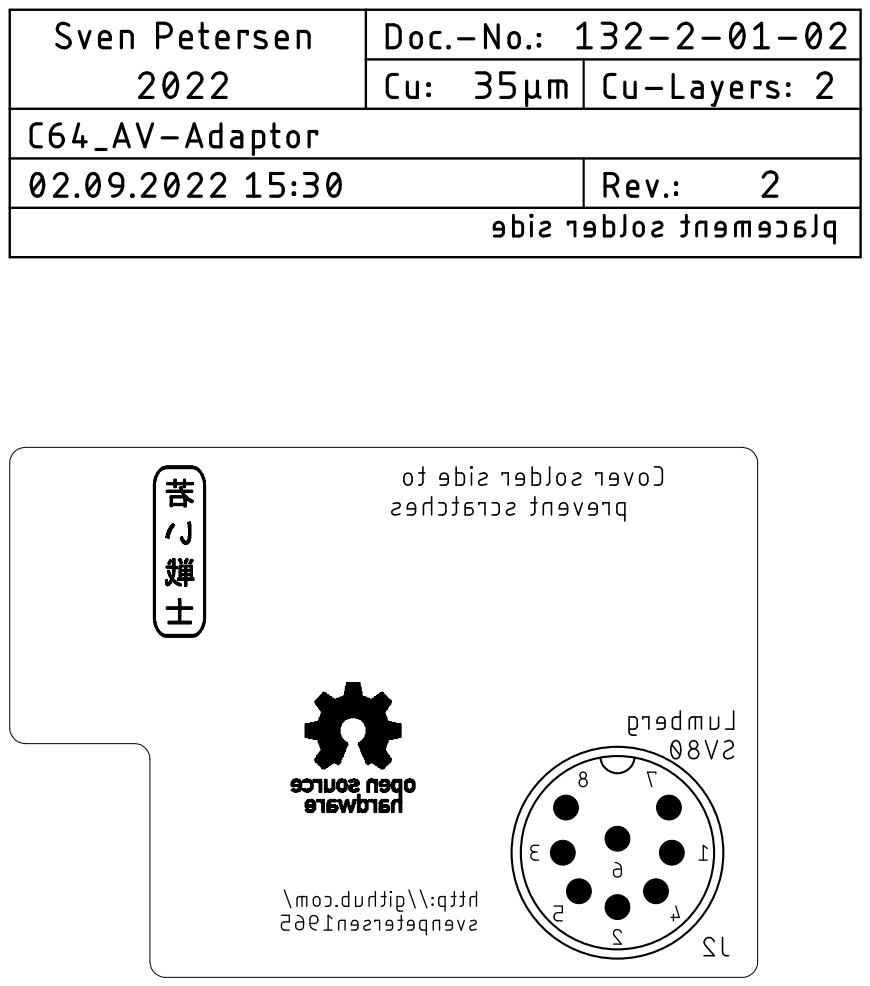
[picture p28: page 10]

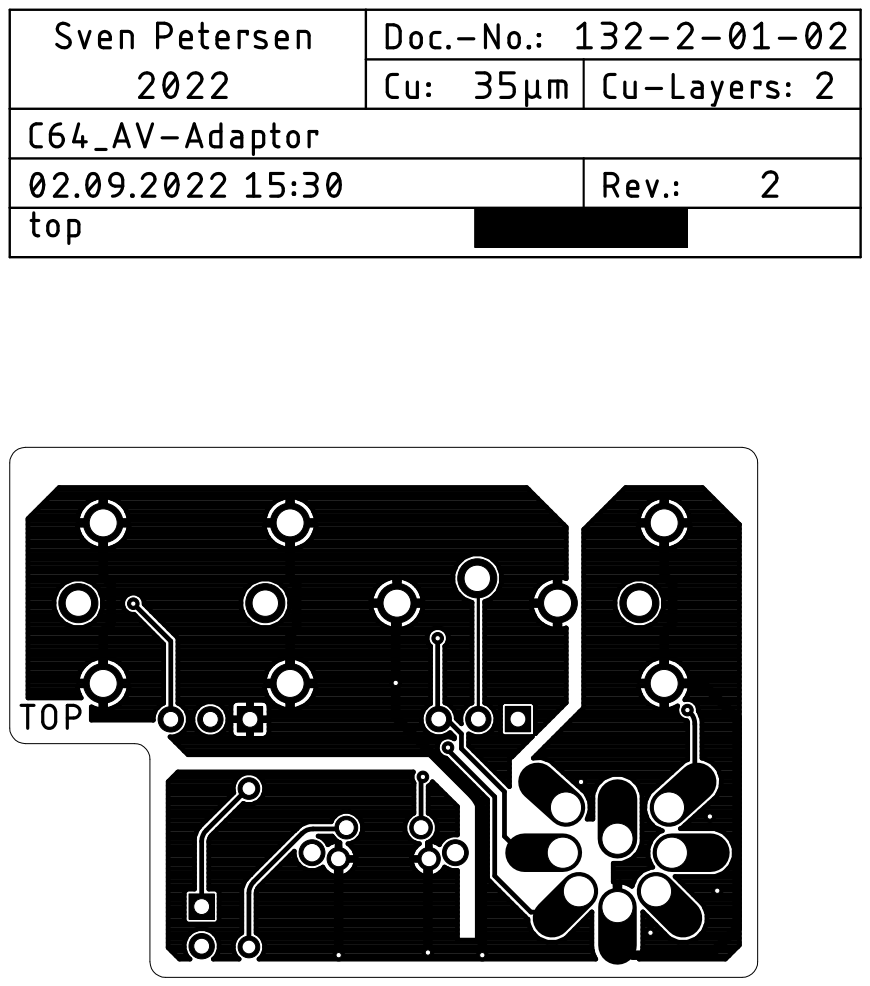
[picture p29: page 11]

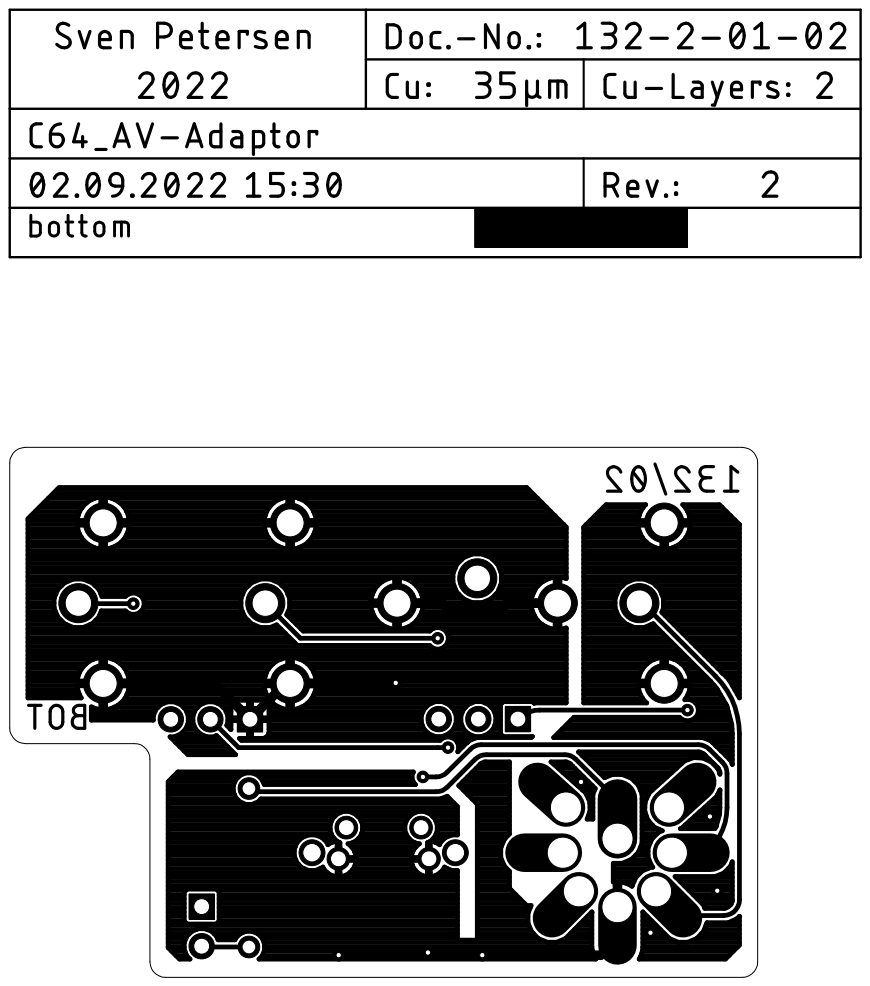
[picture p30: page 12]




C64_AV_Ada_Test_v2.docx | | 02.09.2022 16:03
Drafted by Sven Petersen | Page 1 of 2 | Doc.-No.: 132-6-02-02

### C64 A/V-Adapter Rev. 2

### Testing v2.0

## Introduction

The test was conducted with a prototype of the A/V-Adapter Rev. 2. For the electrical/functional tests a C64G was used.

## Tests

### Assembly

The prototype was assembled, all footprints worked out. The DIN plug was assembled using the spacer, which was cut off the PCB. This worked well, too.

### Mechanical fitting

The A/V-Adaptor was installed on a classic bread bin and a C64C. Both case versions work well with the prototype. It is required to install the DIN plug with a distance to the bottom side of the PCB to get deep enough into the video jack of the C64 to obtain a stabile seating.

### Functional testing

The A/V-adaptor was connected to the C64 and a software was loaded. The jumpers were set to

Jumper | Setting
JP1 (Chroma Hi) | Open (=330R resistor not bridged)
JP2 (Audio in) | Off (audio in → GND)
JP3 (mono/stereo) | Mono (both audio channels connected to J2, Pin 3)
Test | Result | Testing
S-Video cable connected | The displayed image was clear and not distorted | Ok
Audio cable | Both speakers had a clear audio output (mono) | Ok
Composite video | The displayed image was clear and not distorted | Ok
Audio input (JP2 → on) | The audio signal connected was passed through the filter. | Ok
Stereo mode | Multimeter: ok | Ok
Chroma high (s-video), 330R resistor bridged | The quality of the displayed imaged changed. The colors got stronger and slightly distorted. This was expected. | Ok

The stereo mode was tested with a multimeter only.

C64_AV_Ada_Test_v2.docx | | 02.09.2022 16:03
Drafted by Sven Petersen | Page 2 of 2 | Doc.-No.: 132-6-02-02

### Testing of the 5-pin Version

The version for ASSY326298 was tested in an 8-pin C64. Composite video and the Audio outputs
were connected to the Framemeister XRGB mini, the “VIDEO” input was selected. A picture of
expected quality was shown, the sound was audible.

The version for VIC-20 was inserted into a VIC-20. Composite video and the Audio outputs were
connected to the Framemeister XRGB mini, the “VIDEO” input was selected. A picture of expected
quality was shown, the sound was audible.

### 3D-printed cases

After trimming the solder pins of the RCA jacks, all three versions of the board fit into the bottom shell. The respective top shells could be installed and fit well. The decals (labels) fit on the top shell.

The A/V-Adaptors passed a drop test (a drop of 1m on a table top).

## Test Result

The A/V-Adapter Rev. 2 is fully functional.

Pos. Qty Value Footprint Ref.-No. Comment

1 1 132-2-01-02 2 Layer PCB Rev. 2 2 layer, Cu 35µ, HASL, 48.0mm x 34.0mm, 1.6mm FR4

2 2 1x 3p pin header, pitch

2.54mm

1X03 JP2, JP3 standard pin header, e.g. Reichelt RND 205-00624, not

required for 5-pin and VIC-20

3 1 1x 2p pin header, pitch

2.54mm

1X02 JP1 standard pin header, e.g. Reichelt RND 205-00623, not

required for 5-pin and VIC-20

4 3 Jumper 2.54mm pitch jumper (JP1), (JP2), (JP3) Jumper (0,1") with holder/latch, e.g. tme.eu: JUMPER-H/B,
Farnell: 2396301, Newark: 93K5732 , Reichelt: JUMPER
2,54GL SW. Once each for 5-pin and none for VIC-20.

5 1 330R R-10 R1 resistor, 0.25W or more, 5% or better. Not required for 5-

pin and VIC-20

6 1 RCJ-022 RCJ-02X J5 CUI Inc., RCA jack, vertical, red. Mouser: 490-RCJ-022,
Digikey: CP-1407-ND. Alternative part: Keystone 577

7 1 RCJ-023 RCJ-02X J4 CUI Inc., RCA jack, vertical, white. Mouser: 490-RCJ-023,
Digikey: CP-1408-ND. Alternative part: Keystone 584

8 1 RCJ-021 RCJ-02X J3 CUI Inc., RCA jack, vertical, black. Mouser: 490-RCJ-021,
Digikey: CP-1406-ND. Alternative part: Keystone 585

9 1 RCJ-024 RCJ-02X J6 CUI Inc., RCA jack, vertical, yellow. Mouser: 490-RCJ-024,

Digikey: CP-1409-ND. Alternative part: Keystone 586

10 1 RTC9028 MINIDIN4_V J1 Mini-DIN, 4p, vertical. Not required for 5-pin. E.g.

AliExpress:

RTConnector: RTC9028 (https://www.aliexpress.com/item/33032480787.html?spm=a2g0s.9042311.0.0.24354c4dZfdyek)

ebay.de (https://www.ebay.de/itm/5Stuck-Leiterplatten-Mount-4-Pin-Buchse-S-Jack-DVD-Mini-DIN-Sockel-Steckverbind/132869605733)

11 1 SV80 SV80_INNER J2 Inner part of Lumberg 033099 SV 80, e.G. Reichelt: LUM
SV 80, Newark: 23AH4043, Farnell: 1321482, TME.eu:
SV80, alliedelec.com: 70151558. LUM SV 50 for 5-pin

C64 and VIC-20

Rev. History

v0.0 → v0.1

## C64 A/V-Adaptor Rev. 2

## Bill of Material Rev. 2.0

C64_AV_Adapt_BOM_v2_0.xlsx

Drafted by Sven Petersen Page 1 of 2

02.09.2022 15:22
Doc.No.: 132-5-01-02.0

Pos. Qty Value Footprint Ref.-No. Comment

## C64 A/V-Adaptor Rev. 2

## Bill of Material Rev. 2.0

Pos 4 now with latch
three models

v0.1 → v.1.0

Pos 1 PCB revision (no spacer)

v1.0 → v.2.0
Pos 1 PCB Revision

Pos 6 replaced obsolete part

Pos 7 replaced obsolete part

Pos 8 replaced obsolete part

Pos 9 replaced obsolete part

C64_AV_Adapt_BOM_v2_0.xlsx

Drafted by Sven Petersen Page 2 of 2

02.09.2022 15:22
Doc.No.: 132-5-01-02.0

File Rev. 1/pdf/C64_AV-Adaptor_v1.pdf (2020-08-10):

# Project Documentation

## C64 A/V-Adaptor

## Project number: 132

## Revision: 1

## Date: 02.01.2020


C64_AV_Ada_ModD_v1.docx | | 02.01.2020 19:51
Drafted by Sven Petersen | Page 1 of 5 | Doc.-No.: 132-6-01-01

### C64 A/V-Adaptor Rev. 1

### Module Description

## Introduction

The A/V-Adaptor allows to connect standard S-Video and Audio or Composite-Video cables to the A/V-Jack of the Commodore C64.

A 330Ω resistor to attenuate the Chroma signal for S-Video is installed, but it can be deactivated by setting a jumper (JP2). This attenuation is required, since the chroma signal has a level, which is too high for standard S-Video.

Further, the audio input can be connected to GND, in case it is not in use to reduce the noise introduction.

Figure 1: Component side of the A/V-Adaptor

Figure 2: Solder side of the A/V-Adaptor

The two audio output jacks can be connected by a jumper. Alternatively, the stereo sound output (A/V-Jack, pin 7, in case a 2nd SID is installed inside the C64) can be connected to the right channel of the audio output. The first SID output is connected to the left channel of the audio output.

C64_AV_Ada_ModD_v1.docx | | 02.01.2020 19:51
Drafted by Sven Petersen | Page 2 of 5 | Doc.-No.: 132-6-01-01

Since the DIN jack for the C64 (J2) has to be installed with a distance, a soldering aid (spacer) is provided with the PCB. It should be clipped off and put between the PCB and J2 while soldering to keep the right distance and angle. After assembly, it can be discarded.

## Connectors

### A/V-Plug – J2

The A/V-Plug for the C64 is the inner part of a Lumberg 033099 SV 80 DIN-Plug (8 pins, horse shoe = 262°). It provides a round plastic shell of the DIN-connector and long enough pins, so the adaptor can sit firmly in the A/V jack. The inner part of a cheaper (standard) connector cannot be used, since it does not sit firm enough.

Pin Signal
1 Luminance
2 GND
3 Audio Out (mono/left)
4 Composite Video
5 Audio In
6 Chrominance
7 Audio Out (right – if provided) 8 -

### S-Video Jack – J1

A vertical PCB mount Mini-DIN jack (4 circuits)

Pin Signal
1 GND (Luminance)
2 GND (Chrominance)
3 Luminance
4 Chrominance

### RCA-Jacks – J3, J4, J5 & J6

Connector Signal
J3 | Audio Out (mono/left)
J4 | Audio Out (mono/right)
J5 | Audio In
J6 | Composite Video

## Jumpers

### Chrominance attenuation – JP1

The chrominance signal has a too high level for the standard S-Video chroma signal. The jumper bridges the 330Ω resistor (R1) to switch off this attenuation.

Status Configuration
open | Attenuation active
set | Attenuation inactive/off


C64_AV_Ada_ModD_v1.docx | | 02.01.2020 19:51
Drafted by Sven Petersen | Page 3 of 5 | Doc.-No.: 132-6-01-01

### Audio Input Off – JP2

To reduce the noise introduction to the Audio Input, this can be grounded.

Status Configuration
ON | SID Audio In connected to J5
OFF | SID Audio In connected to GND

### Mono/Stereo – JP3

The standard audio output of the SID is one channel (mono). In cases a 2nd SID is installed, the 2nd audio output is (usually) connected to Pin 7 of the Audio/Video jack of the C64. JP3 connected the right channel of the audio output (J4) to either J2, Pin 3 or Pin 7.

Status | Configuration
MONO | J4 connected to J2, Pin 3
STEREO | J4 connected to J2, Pin 7

## Assembly

Install the DIN plug (J2) on the solder side (bottom) first. Put the PCB on a suitable surface, the solder side up. Insert the DIN-plug, make sure, it is vertical and solder one pin first (from the solder side, which is pointing up, refer to Figure 3). Check again that the plug is straight, correct if required and finally solder all other pins.

Figure 3: Soldering the DIN-plug J2

Figure 4: DIN-plug seen from the component side ("TOP")

Install and solder all other components from the component side. Watch the angle of the components, solder them from the solder side. Clip excess pin length.


C64_AV_Ada_ModD_v1.docx | | 02.01.2020 19:51
Drafted by Sven Petersen | Page 4 of 5 | Doc.-No.: 132-6-01-01

In case no enclosure is used, cover the solder side (except J2) with duct tape to prevent scratching the case of the C64.

## Versions for the ASSY 326298 (5-pin) and the VIC-20

ASSY 326298 was the first model of the C64, which was built in 1982. It did not have all S-Video signals. Chroma is missing. Thus, a 5-pin DIN plug is required for J2. The S-Video jack (J1) is not required.

Figure 5: The three models of the A/V-Adaptor

The VIC-20 also requires a 5-pin DIN plug but no Audio-in RCA jack.

Component | C64 regular | C64 ASSY326298 | VIC-20
J2 (DIN) | SV 80 (8 pin) | SV 50 (5 pin) | SV 50 (5 pin)
J1 (S-Video) | populate | do not populate | do not populate
J5 (RCA: Audio in) | populate | populate | do not populate
JP1 (Chroma 330Ω) | populate | do not populate | do not populate
JP2 (Audio In) | populate | populate | do not populate
JP3 (mono/stereo) | populate | hardwire to mono | hardwire to mono
R1 (330Ω) | populate | do not populate | do not populate

SV 80 and SV 50 are Lumberg components.

Figure 6: JP3 hardwired to mono

JP3 can be hardwired using a short piece of wire.

C64_AV_Ada_ModD_v1.docx | | 02.01.2020 19:51
Drafted by Sven Petersen | Page 5 of 5 | Doc.-No.: 132-6-01-01

## Revision History

### Rev. 0 → Rev. 1

Spacer was removed from the design.









C64_AV_Ada_Test_0_1.docx | | 02.01.2020 19:55
Drafted by Sven Petersen | Page 1 of 2 | Doc.-No.: 132-6-02-01

### C64 A/V-Adaptor Rev. 1

### Testing v0.1

## Introduction

The test was conducted with a prototype of the A/V-Adaptor Rev. 0. For the electrical/functional tests a C64G was used.

## Tests

### Assembly

The prototype was assembled, all footprints worked out. The DIN plug was assembled using the spacer, which was cut off the PCB. This worked well, too.

### Mechanical fitting

The A/V-Adaptor was installed on a classic bread bin and a C64C. Both case versions work well with the prototype. It is required to install the DIN plug with a distance to the bottom side of the PCB to get deep enough into the video jack of the C64 to obtain a stabile seating.

### Functional testing

The A/V-adaptor was connected to the C64 and a software was loaded. The jumpers were set to

Jumper | Setting
JP1 (Chroma Hi) | Open (=330R resistor not bridged)
JP2 (Audio in) | Off (audio in → GND)
JP3 (mono/stereo) | Mono (both audio channels connected to J2, Pin 3)
Test | Result | Testing
S-Video cable connected | The displayed image was clear and not distorted | Ok
Audio cable | Both speakers had a clear audio output (mono) | Ok
Composite video | The displayed image was clear and not distorted | Ok
Audio input (JP2 → on) | The audio signal connected was passed through the filter. | Ok
Stereo mode | TBD | TBD
Chroma high (s-video), 330R resistor bridged | The quality of the displayed imaged changed. The colors got stronger and slightly distorted. This was expected. | Ok

The stereo mode was not tested.

C64_AV_Ada_Test_0_1.docx | | 02.01.2020 19:55
Drafted by Sven Petersen | Page 2 of 2 | Doc.-No.: 132-6-02-01

### Testing of the 5-pin Version

The version for ASSY326298 was tested in an 8-pin C64. Composite video and the Audio outputs
were connected to the Framemeister XRGB mini, the “VIDEO” input was selected. A picture of
expected quality was shown, the sound was audible.

The version for VIC-20 was inserted into a VIC-20. Composite video and the Audio outputs were
connected to the Framemeister XRGB mini, the “VIDEO” input was selected. A picture of expected
quality was shown, the sound was audible.

### 3D-printed cases

After trimming the solder pins of the RCA jacks, all three versions of the board fit into the bottom shell. The respective top shells could be installed and fit well. The decals (labels) fit on the top shell.

The A/V-Adaptors passed a drop test (a drop of 1m on a table top).

## Test Result

The A/V-Adaptor is fully functional.

Pos. Qty Value Footprint Ref.-No. Comment

1 1 132-2-01-01 2 Layer PCB Rev. 1 2 layer, Cu 35µ, HASL, 48.0mm x 34.0mm, 1.6mm FR4

2 2 1x 3p pin header, pitch

2.54mm

1X03 JP2, JP3 standard pin header, e.g. Reichelt RND 205-00624, not

required for 5-pin and VIC-20

3 1 1x 2p pin header, pitch

2.54mm

1X02 JP1 standard pin header, e.g. Reichelt RND 205-00623, not

required for 5-pin and VIC-20

4 3 Jumper 2.54mm pitch jumper (JP1), (JP2), (JP3) Jumper (0,1") with holder/latch, e.g. tme.eu: JUMPER-H/B,
Farnell: 2396301, Newark: 93K5732 , Reichelt: JUMPER
2,54GL SW. Once each for 5-pin and none for VIC-20.

5 1 330R R-10 R1 resistor, 0.25W or more, 5% or better. Not required for 5-

pin and VIC-20

6 1 BTOR1 (black) BTOR1 J5 Lumberg, RCA jack, vertical, black. E.G. Reichelt LUM
BTOR1 SW, Farnell: 1217030, Newark: 96K7172,

TME.eu: BTOR1B, Not required for VIC-20

7 1 BTOR1 RED BTOR1 J4 Lumberg, RCA jack, vertical, red. E.G. Reichelt LUM BTOR1

RT, Farnell: 1368644, Newark: 53M6863, TME.eu:

BTOR1R

8 1 BTOR1 WHITE BTOR1 J3 Lumberg, RCA jack, vertical, white. E.G. Reichelt LUM
BTOR1 WS, Farnell: 1368645, Newark: 53M6864,

TME.eu: BTOR1W

9 1 BTOR1 YELLOW BTOR1 J6 Lumberg, RCA jack, vertical, yellow. E.G. Reichelt LUM
BTOR1 GE, Farnell: 1368642, Newark: 53M6865,

TME.eu: BTOR1Y

10 1 RTC9028 MINIDIN4_V J1 Mini-DIN, 4p, vertical. Not required for 5-pin and VIC-20.

E.g. AliExpress:

RTConnector: RTC9028 (https://www.aliexpress.com/item/33032480787.html?spm=a2g0s.9042311.0.0.24354c4dZfdyek)

ebay.de (https://www.ebay.de/itm/5Stuck-Leiterplatten-Mount-4-Pin-Buchse-S-Jack-DVD-Mini-DIN-Sockel-Steckverbind/132869605733)

## C64 A/V-Adaptor Rev. 1

## Bill of Material Rev. 1.0

C64_AV_Adapt_BOM_v1_0.xlsx

Drafted by Sven Petersen Page 1 of 2

02.01.2020 20:00
Doc.No.: 132-5-01-01.0

Pos. Qty Value Footprint Ref.-No. Comment

## C64 A/V-Adaptor Rev. 1

## Bill of Material Rev. 1.0

11 1 SV80 SV80_INNER J2 Inner part of Lumberg 033099 SV 80, e.G. Reichelt: LUM
SV 80, Newark: 23AH4043, Farnell: 1321482, TME.eu:
SV80, alliedelec.com: 70151558. LUM SV 50 for 5-pin

C64 and VIC-20

Rev. History

v0.0 → v0.1

Pos 4 now with latch
three models

v0.1 → v.1.0

Pos 1 PCB revision (no spacer)

C64_AV_Adapt_BOM_v1_0.xlsx

Drafted by Sven Petersen Page 2 of 2

02.01.2020 20:00
Doc.No.: 132-5-01-01.0

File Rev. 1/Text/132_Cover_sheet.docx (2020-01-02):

Project Documentation

C64 A/V-Adaptor

Project number: 132

Revision: 1

Date: 02.01.2020


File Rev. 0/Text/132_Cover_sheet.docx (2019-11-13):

Project Documentation

C64 A/V-Adaptor

Project number: 132

Revision: 0

Date: 08.08.2019


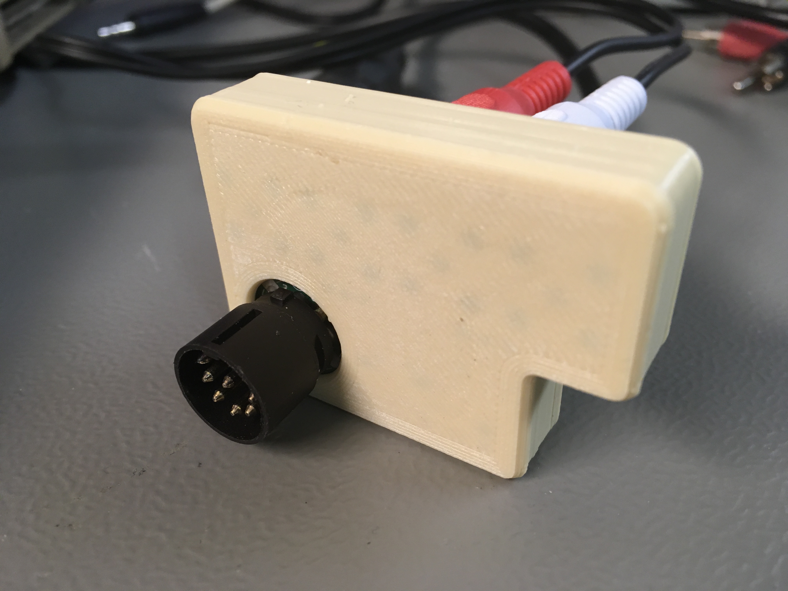
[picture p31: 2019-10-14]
case/Rev. 0/pictures/2865_-_adaptor_back.JPG

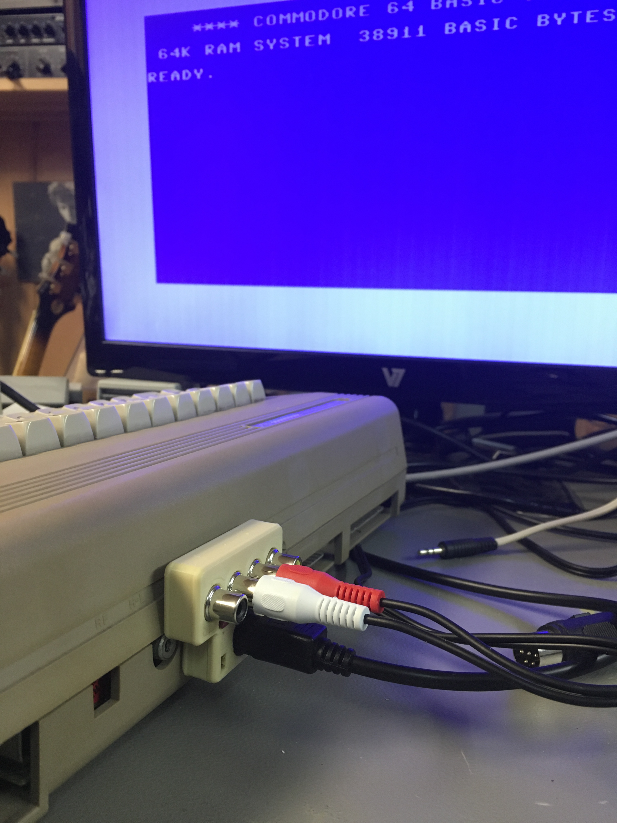
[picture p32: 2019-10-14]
case/Rev. 0/pictures/2863_-_adaptor_with_C64_side.JPG

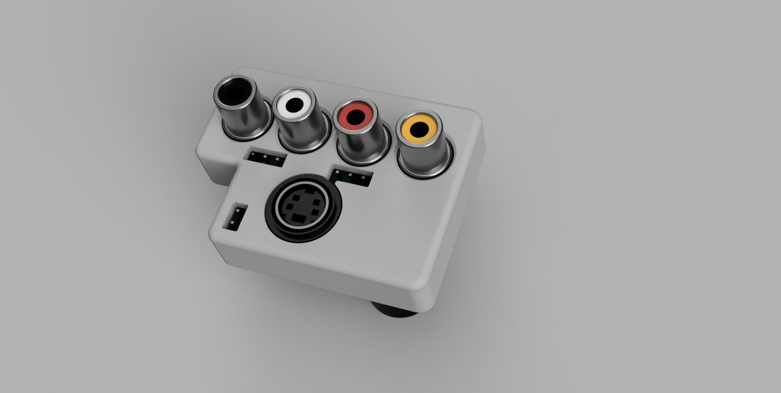
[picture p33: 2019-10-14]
case/Rev. 0/pictures/AV-Adaptor_case_closed.png

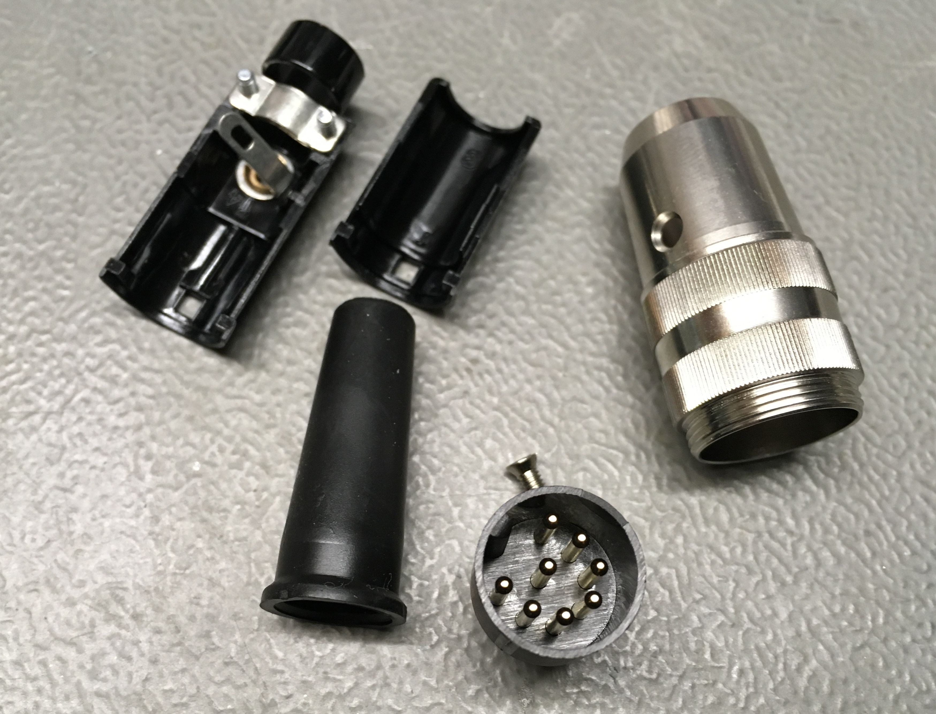
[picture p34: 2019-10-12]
Rev. 2/pictures/2813_-_lumberg_sv80.JPG

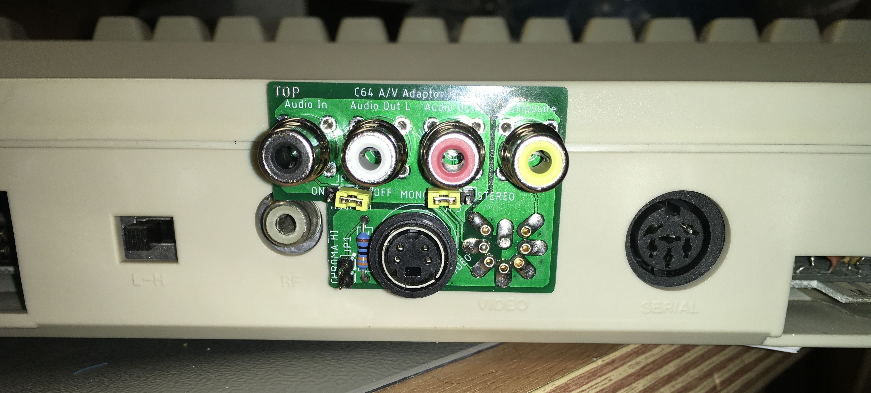
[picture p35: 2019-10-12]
Rev. 2/pictures/2821_-_av-adaptor_C64C.JPG

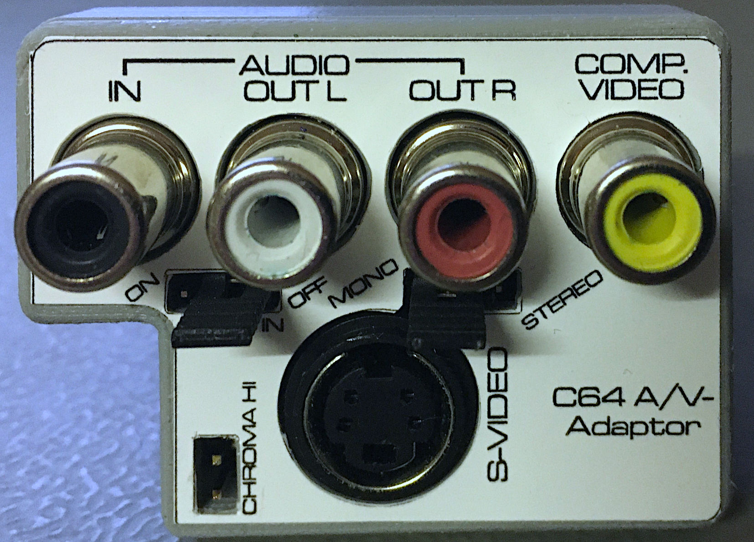
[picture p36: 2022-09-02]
Rev. 2/pictures/3436_c64_AV_adaptor.JPG

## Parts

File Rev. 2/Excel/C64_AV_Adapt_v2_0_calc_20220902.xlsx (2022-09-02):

C64 A/V-Adaptor Rev. 2
Calculation
Pos. | Qty | Value | Footprint | €/each | total
1 | 1 | 132-2-01-02 | 2 Layer | 1.00 € | 1.00 €
2 | 2 | 1x 3p pin header, pitch 2.54mm | 1X03 | 0.10 € | 0.20 €
3 | 1 | 1x 2p pin header, pitch 2.54mm | 1X02 | 0.10 € | 0.10 €
4 | 3 | Jumper 2.54mm pitch | jumper | 0.10 € | 0.30 €
5 | 1 | 330R | R-10 | 0.10 € | 0.10 €
6 | 1 | RCJ-022 | RCJ-02X | 1.36 € | 1.36 €
7 | 1 | RCJ-023 | RCJ-02X | 1.36 € | 1.36 €
8 | 1 | RCJ-021 | RCJ-02X | 1.36 € | 1.36 €
9 | 1 | RCJ-024 | RCJ-02X | 1.36 € | 1.36 €
10 | 1 | RTC9028 | MINIDIN4_V | 1.00 € | 1.00 €
11 | 1 | SV80 | SV80_INNER | 5.99 € | 5.99 €
12 | 1 | case |  | 2.50 € | 2.50 €
 |  |  |  | Total | 16.63 €

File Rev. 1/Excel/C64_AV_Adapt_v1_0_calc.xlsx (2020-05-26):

C64 A/V-Adaptor Rev. 1
Calculation
Pos. | Qty | Value | Footprint | €/each | total
1 | 1 | 132-2-01-01 | 2 Layer | 1.00 € | 1.00 €
2 | 2 | 1x 3p pin header, pitch 2.54mm | 1X03 | 0.10 € | 0.20 €
3 | 1 | 1x 2p pin header, pitch 2.54mm | 1X02 | 0.10 € | 0.10 €
4 | 3 | Jumper 2.54mm pitch | jumper | 0.10 € | 0.30 €
5 | 1 | 330R | R-10 | 0.10 € | 0.10 €
6 | 1 | BTOR1 (black) | BTOR1 | 0.70 € | 0.70 €
7 | 1 | BTOR1 RED | BTOR1 | 0.70 € | 0.70 €
8 | 1 | BTOR1 WHITE | BTOR1 | 0.70 € | 0.70 €
9 | 1 | BTOR1 YELLOW | BTOR1 | 0.70 € | 0.70 €
10 | 1 | RTC9028 | MINIDIN4_V | 1.00 € | 1.00 €
11 | 1 | SV80 | SV80_INNER | 4.75 € | 4.75 €
12 | 1 | case |  | 2.50 € | 2.50 €
 |  |  |  | Total | 12.75 €

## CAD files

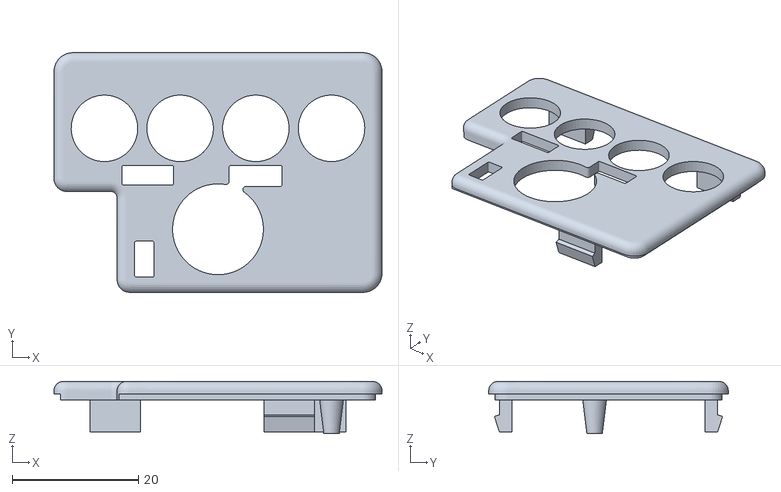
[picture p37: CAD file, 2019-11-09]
case/Rev. 0/stl/top shell regular.stl
52.0 x 38.0 x 8.30

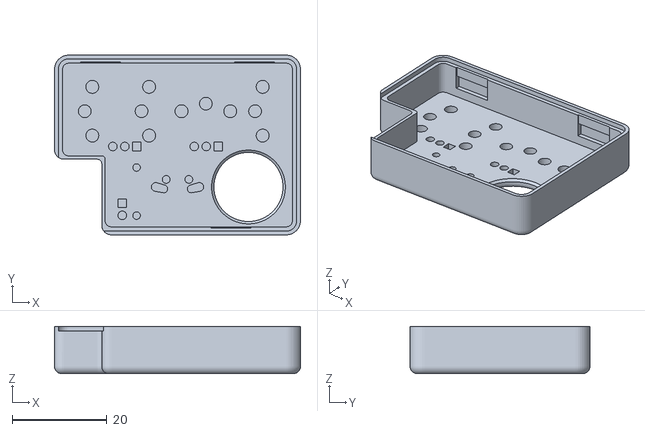
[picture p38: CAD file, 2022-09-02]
case/Rev. 2/stl/C64AV bottom shell v2.stl
52.0 x 38.0 x 10.0

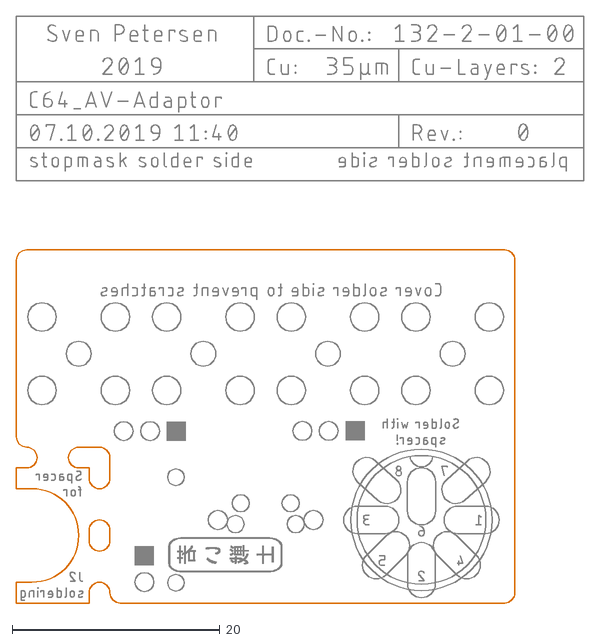
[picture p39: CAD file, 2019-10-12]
Rev. 0/dxf/C64_AV-Adaptor_bplace_bstop.dxf
54.6 x 56.5

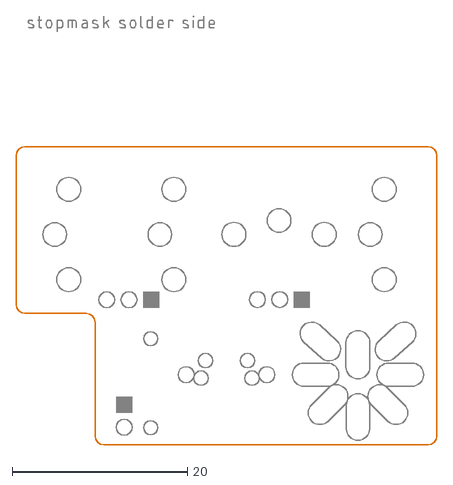
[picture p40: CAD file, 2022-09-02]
Rev. 2/dxf/C64_AV-Adaptor_smb.dxf
48.0 x 48.9

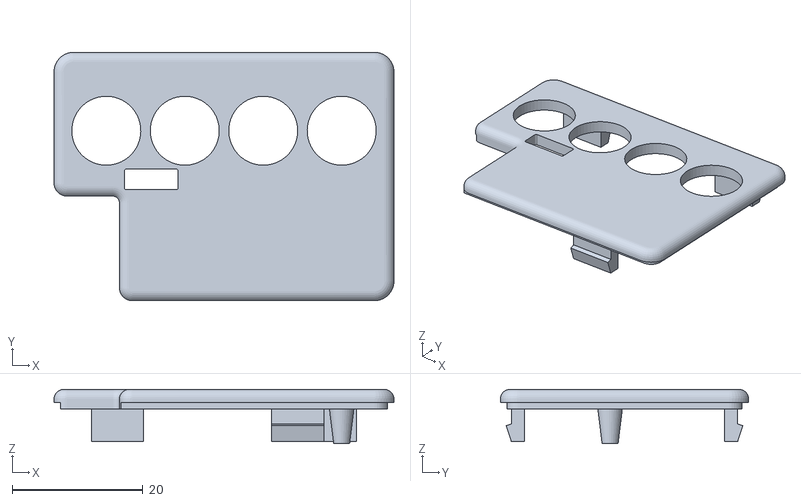
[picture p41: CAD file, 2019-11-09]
case/Rev. 0/stl/top shell 5 pin.stl
52.0 x 38.0 x 8.30

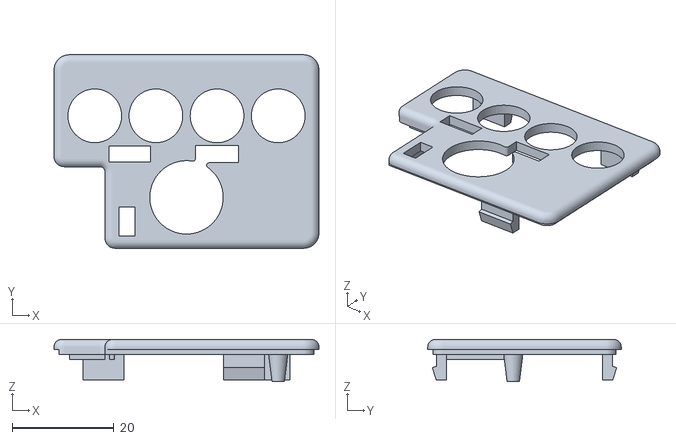
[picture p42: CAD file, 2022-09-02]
case/Rev. 2/stl/C64AV top shell v2.stl
52.0 x 38.0 x 8.30

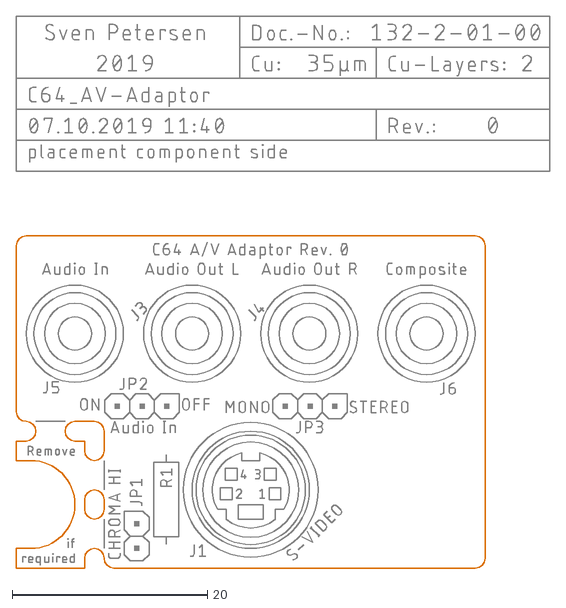
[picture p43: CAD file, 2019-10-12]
Rev. 0/dxf/C64_AV-Adaptor_top.dxf
54.6 x 56.5

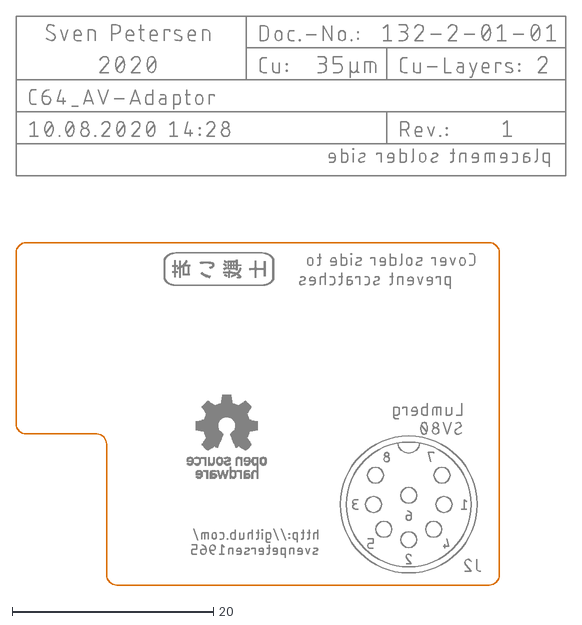
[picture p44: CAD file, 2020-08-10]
Rev. 2/dxf/C64_AV-Adaptor_bottom.dxf
54.6 x 56.5

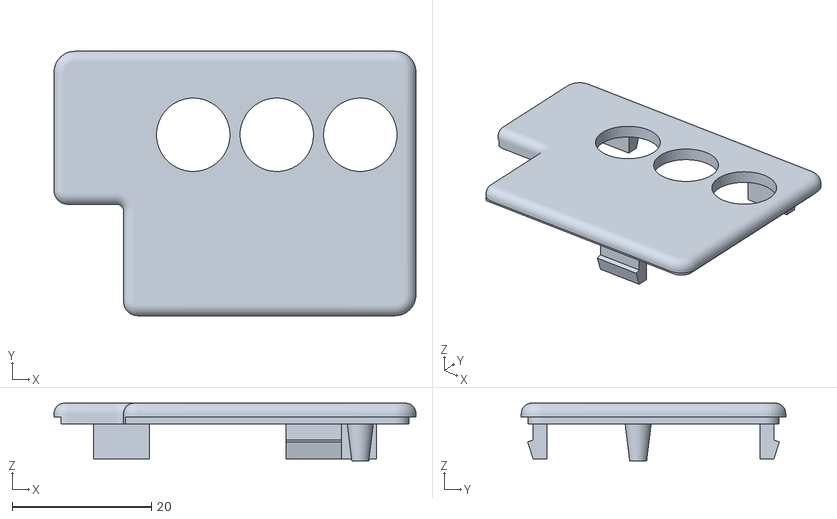
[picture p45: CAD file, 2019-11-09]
case/Rev. 0/stl/top shell VIC-20.stl
52.0 x 38.0 x 8.30

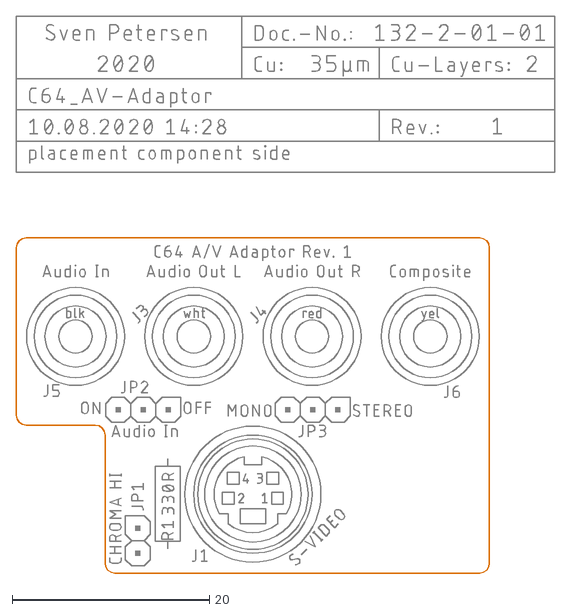
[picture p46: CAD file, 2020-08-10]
Rev. 2/dxf/C64_AV-Adaptor_top.dxf
54.6 x 56.5

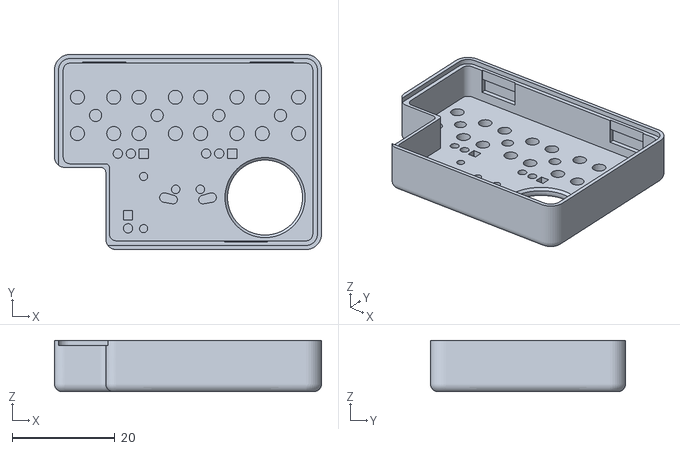
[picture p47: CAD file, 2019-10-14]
case/Rev. 0/stl/bottom shell.stl
52.0 x 38.0 x 10.0

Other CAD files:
case/Rev. 0/Fusion 360/AV-Adaptor_case v10.f3d
case/Rev. 0/Fusion 360/AV-Adaptor_case v18.f3d
case/Rev. 0/Fusion 360/AV-Adaptor_case_5pin v8.f3d
case/Rev. 0/Fusion 360/AV-Adaptor_case_VIC-20 v10.f3d
case/Rev. 2/Fusion 360/AV-Adaptor_case_v2 v3.f3d

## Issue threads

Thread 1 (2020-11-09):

BOM Request

ptdecker, 2020-11-09:
Hello!

I had a set of six of your boards made.  I'm now trying to locate the parts.  Could you recommend a part number and supplier for your RCA jacks and the S-Video plug?  All the RCA jacks I am finding do not have the pin arrangements (four in a square plus one center).  Also, I have tried Allied but have not had any luck finding a PCB mount for the 8-pin DIN.  Specific part numbers would be awesome for it as well.

(BTW, the boards are well done!  Nice work!)

P. Todd

svenpetersen1965, 2020-11-10:
Did you check the BOM? [https://github.com/svenpetersen1965/C64-A-V-Adaptor/tree/master/Rev.%201/Excel](url)
There are the specific manufacturers, part numbers and some sources included.

ptdecker, 2020-11-10:
My apology.  I did not see these the first time.

svenpetersen1965, 2020-11-10:
No problem :-)

Closed 2020-11-10.

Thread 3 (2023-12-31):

Audio In needs attenuation

gsteemso, 2023-12-31:
As I understand it, a standard audio "line in" level has s maximum of 0.7 V.  However, per the data sheet, a SID chip accepts a maximum of 0.6 V.  (I'm not sure if these are peak-to-peak or peak-to-ground measurements.)  The only reason I have never dared to use my Commodore's audio input line - which I would very much like to try, as SIDs were designed to be daisy-chainable - is because of this issue.  If doing so fries my SID, there are no more _real_ ones to replace it with, only reimplementations of varying accuracy.

svenpetersen1965, 2024-01-03:
Hi,
Please excuse my delayed reply. I wasn’t feeling so well.

Maybe, we have different data sheets. The one I have specifies the voltage on the Pin ExtIn (Pin 26) as follows:
„Any voltage applied directly to the pin should ride at dc level of 6 volts and should not exceed 3 volt p-p“

That is on page 8 of the data sheet. Unfortunately, it is neither marked with a date nor a version.

The audio in pin on the A/V jack is ac coupled with a 100nF cap. The data sheet actually requests a capacitor of 1 to 10μF. So right now, I don’t see a problem here.

Regards,
Sven

gsteemso, 2024-01-27:
After some digging, it looks like thd one I saw was a preliminary version.  It containing a figure that was off by one decimal position makes sense.  A great relief!

Marking this closed.

Closed 2024-01-27.

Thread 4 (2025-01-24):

Odd horizontal flickering when using the device on a sx64

dlannan, 2025-01-24:
I bought one of your devices (not yours specifically, it looks like someone is printing and selling them on ebay).
What was odd/disappointing/frustrating was that when I changed from using a C64 video cable to this, hoping it would be at least a little improved (better chroma/luma handling) and it was substantially worse.
Heres some screenshots:
Svideo - note the diagonal signal issues. This flickers horribly.
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
Composite - Much more noticable but not overally different in how bad it is live.
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

Using the normal C64 cable.
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

The creator also bent the red audio pin, but I dont think this is all that important.

Now I know you shouldnt be servicing others work. So I dont ask for that. What I was hoping, is if you could give me some tips/hints on how this might be improved to be at least as good as the cable.

I wondered if I should resolder the joints (they didnt look great).
Or is there something else that could be cause this - short or bridge somewhere causing interference on the luma line?
Im tempted to make my own, to make sure its built properly.
Thanks for a great product tho. Any help would be greatly appreciated.

svenpetersen1965, 2025-01-24:
 Hi David,could you show a picture of the component (especially the DIN connector), and tell me, where you have bought it, please. A decrease in quality can have two reasons:1. Something is wrong with the adapter2. Something is wrong with the cablesI suppose, it is 1.I have seen the adapter being sold on Amazon for a pretty low price, which is basically good. I didn’t see the DIN connector, though. I suppose, it is not a good one, but a very ordinary insert of a DIN connector for 50 cents. So it only has pins, but not the cylinder, that holds the adapter in position. This way, a mechanical load is applied, sideways to the pins, which might not produce a save contact and stresses the terminals of the C64.Next is a bad solder joint. So, reflowing the solder might be, what you could do. I have heard, that my adapter does miracle things, which it cannot, because there is no miracle device inside, but it does less harmful things to the video signal, than some botched C64 video cables with all soldering inside the case of a DIN connector. Did you try pulling the jumper for chroma hi/low, yet? Mit freundlichen Grüßen/Kind regardsSven PetersenAm 24.01.2025 um 04:31 schrieb David Lannan ***@***.***>:
I bought one of your devices (not yours specifically, it looks like someone is printing and selling them on ebay).
What was odd/disappointing/frustrating was that when I changed from using a C64 video cable to this, hoping it would be at least a little improved (better chroma/luma handling) and it was substantially worse.
Heres some screenshots:
Svideo - note the diagonal signal issues. This flickers horribly.
IMG_20250124_131452143_svideo.jpg (view on web)
Composite - Much more noticable but not overally different in how bad it is live.
IMG_20250124_131404931_composite.jpg (view on web)
Using the normal C64 cable.
IMG_20250124_131258905_c64_cable.jpg (view on web)
The creator also bent the red audio pin, but I dont think this is all that important.
Now I know you shouldnt be servicing others work. So I dont ask for that. What I was hoping, is if you could give me some tips/hints on how this might be improved to be at least as good as the cable.
I wondered if I should resolder the joints (they didnt look great).
Or is there something else that could be cause this - short or bridge somewhere causing interference on the luma line?
Im tempted to make my own, to make sure its built properly.
Thanks for a great product tho. Any help would be greatly appreciated.

—Reply to this email directly, view it on GitHub, or unsubscribe.You are receiving this because you are subscribed to this thread.Message ID: ***@***.***>

dlannan, 2025-01-24:
Hi Sven,
Thank you so much for your fast response. I really appreciate your time.
Heres where I bought it:
https://www.ebay.com.au/itm/386150548088

Heres a couple of shots of the board. Without really knowing much about the circuit myself, some of the solder joints seen to connect points inadvertently. Im assuming they are prob grounds so it shouldnt really matter.

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

I did try the chroma jumper with it and without it. I couldnt see any perceivable difference?
I should note, I also pass the composite/svideo into a retro scale 2x device, which has traditionally for many of my machines (Amigas, C64's, ZX's and others) been very good. The main thing that is puzzling is the fact the cable - which as you note, most c64 cables are pretty dodgy is quite good video out, but the device I bought is not (your design not your device :) .. dont wanna blame you or anything).

I think reflowing the solder joints might be the best thing to try. Might give that a try. It might have just been rushed - the red audio connector clearly was. So it might explain it.

dlannan, 2025-01-24:
Added another shot of the board:

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

svenpetersen1965, 2025-01-24:
Hi again, David,
that DIN connector is fine.

I think, it might be a bad solder joint. Or the connector is dirty. If they have done any quality control, the adapter should not have been sold this way. It is obviously not ok.

I have had a problem with an adapter, that I have built some times ago. It was a bad solder joint (which doesn’t happen to me very often). I had to open the case and reflow the joints. Then it was ok. I think, maybe, it is at the DIN connector. Did you try using the S-Video instead of composite video?

Mit freundlichen Grüßen/Kind regards
Sven Petersen

dlannan, 2025-01-24:
Thanks Sven. I agree, I'll try redoing the solder joints on the din especially. Some of them look a little odd.
Yes I tried the svideo (shown above) its not as bad from the screenshot. But when seen live it flickers as much as the composite. So your point about being something on the DIN is probably it. Thanks again for your time.
I really appreciate it. And thanks for the device, I hope I can get it working nicely :)

svenpetersen1965, 2025-01-24:
Hi David,I have already tried that blue/red 2x retro scaler. It works and is most likely not the cause of the problem. If you pull that chroma jumper, it should have an influence, in case you use the s-video output. For composite, it does not do anything, since that does not use the separate chroma. For S-Video, the jumper shorts the 330Ω resistor in the (separate) chroma signal, when it is set. Please let me know, if and what has helpedMit freundlichen Grüßen/Kind regardsSven Petersen

—Reply to this email directly, view it on GitHub, or unsubscribe.You are receiving this because you commented.Message ID: ***@***.***>

dlannan, 2025-01-26:
Update:  I resoldered everything. I also checked my c64 cable one, and it only used 4 pins. So I de-soldered to match it and still had the interference. I think there might be some sort of leakage but I resistance checked and found nothing. I have an oscilloscope and if I have some spare time I might try to see if I can determine what the signal noise source is from.

svenpetersen1965, 2025-01-26:
It is very strange. Could it be dirt inside a connector? That could cause a capacitive connection instead of a low resistance? Could it be a ground loop? Like between the audio and the video cable? So, what happens if you only connect a video cable and not composite video an svideo at the same time?
Greetings, Sven

dlannan, 2025-01-26:
Dirt inside the connector - thats an interesting point.I have been testing for resistance from the back of the connector. It may even be the pin material itself. I think when I get some time to do some signal testing, it might become more clear. It is certainly odd.
The ground loop seemed pretty good - checked for any resistance between ground and other connections.
I'll try disabling the svideo and see if I can check. It _should_ be the same at the 4 pin video (thats my understanding). Will let you know what I find. Probably wont get to it until next weekend.

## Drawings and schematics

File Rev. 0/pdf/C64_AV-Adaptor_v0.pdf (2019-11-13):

# Project Documentation

## C64 A/V-Adaptor

## Project number: 132

## Revision: 0

## Date: 08.08.2019



C64_AV_Ada_ModD_v0_1.docx | | 13.11.2019 14:52
Drafted by Sven Petersen | Page 1 of 4 | Doc.-No.: 132-6-01-00.1

### C64 A/V-Adaptor Rev. 0

### Module Description v0.1

## Introduction

The A/V-Adaptor allows to connect standard S-Video and Audio or Composite-Video cables to the A/V-Jack of the Commodore C64.

A 330Ω resistor to attenuate the Chroma signal for S-Video is installed, but it can be deactivated by setting a jumper (JP2). This attenuation is required, since the chroma signal has a level, which is too high for standard S-Video.

Further, the audio input can be connected to GND, in case it is not in use to reduce the noise introduction.

Figure 1: Component side of the A/V-Adaptor

Figure 2: Solder side of the A/V-Adaptor

The two audio output jacks can be connected by a jumper. Alternatively, the stereo sound output (A/V-Jack, pin 7, in case a 2nd SID is installed inside the C64) can be connected to the right channel of the audio output. The first SID output is connected to the left channel of the audio output.

C64_AV_Ada_ModD_v0_1.docx | | 13.11.2019 14:52
Drafted by Sven Petersen | Page 2 of 4 | Doc.-No.: 132-6-01-00.1

Since the DIN jack for the C64 (J2) has to be installed with a distance, a soldering aid (spacer) is provided with the PCB. It should be clipped off and put between the PCB and J2 while soldering to keep the right distance and angle. After assembly, it can be discarded.

## Connectors

### A/V-Plug – J2

The A/V-Plug for the C64 is the inner part of a Lumberg 033099 SV 80 DIN-Plug (8 pins, horse shoe = 262°). It provides a round plastic shell of the DIN-connector and long enough pins, so the adaptor can sit firmly in the A/V jack. The inner part of a cheaper (standard) connector cannot be used, since it does not sit firm enough.

Pin Signal
1 Luminance
2 GND
3 Audio Out (mono/left)
4 Composite Video
5 Audio In
6 Chrominance
7 Audio Out (right – if provided) 8 -

### S-Video Jack – J1

A vertical PCB mount Mini-DIN jack (4 circuits)

Pin Signal
1 GND (Luminance)
2 GND (Chrominance)
3 Luminance
4 Chrominance

### RCA-Jacks – J3, J4, J5 & J6

Connector Signal
J3 | Audio Out (mono/left)
J4 | Audio Out (mono/right)
J5 | Audio In
J6 | Composite Video

## Jumpers

### Chrominance attenuation – JP1

The chrominance signal has a too high level for the standard S-Video chroma signal. The jumper bridges the 330Ω resistor (R1) to switch off this attenuation.

Status Configuration
open | Attenuation active
set | Attenuation inactive/off

C64_AV_Ada_ModD_v0_1.docx | | 13.11.2019 14:52
Drafted by Sven Petersen | Page 3 of 4 | Doc.-No.: 132-6-01-00.1

### Audio Input Off – JP2

To reduce the noise introduction to the Audio Input, this can be grounded.

Status Configuration
ON | SID Audio In connected to J5
OFF | SID Audio In connected to GND

### Mono/Stereo – JP3

The standard audio output of the SID is one channel (mono). In cases a 2nd SID is installed, the 2nd audio output is (usually) connected to Pin 7 of the Audio/Video jack of the C64. JP3 connected the right channel of the audio output (J4) to either J2, Pin 3 or Pin 7.

Status | Configuration
MONO | J4 connected to J2, Pin 3
STEREO | J4 connected to J2, Pin 7

## Assembly

Install the A/V plug (J2) on the solder side (bottom) by putting the spacer, which is provided as a part of the PCB, between the PCB and the plug. Make sure, it is parallel to the board. Solder it from the component side. A distance of at least 1.6mm is required (the thickness of the spacer is 1.6mm), 2mm is even better.

Install and solder all other components from the component side. Watch the angle of the components, solder them from the solder side. Clip excess pin length.

Cover the solder side (except J2) with duct tape to prevent scratching the case of the C64.

A 3D-printed case is the better solution here.
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

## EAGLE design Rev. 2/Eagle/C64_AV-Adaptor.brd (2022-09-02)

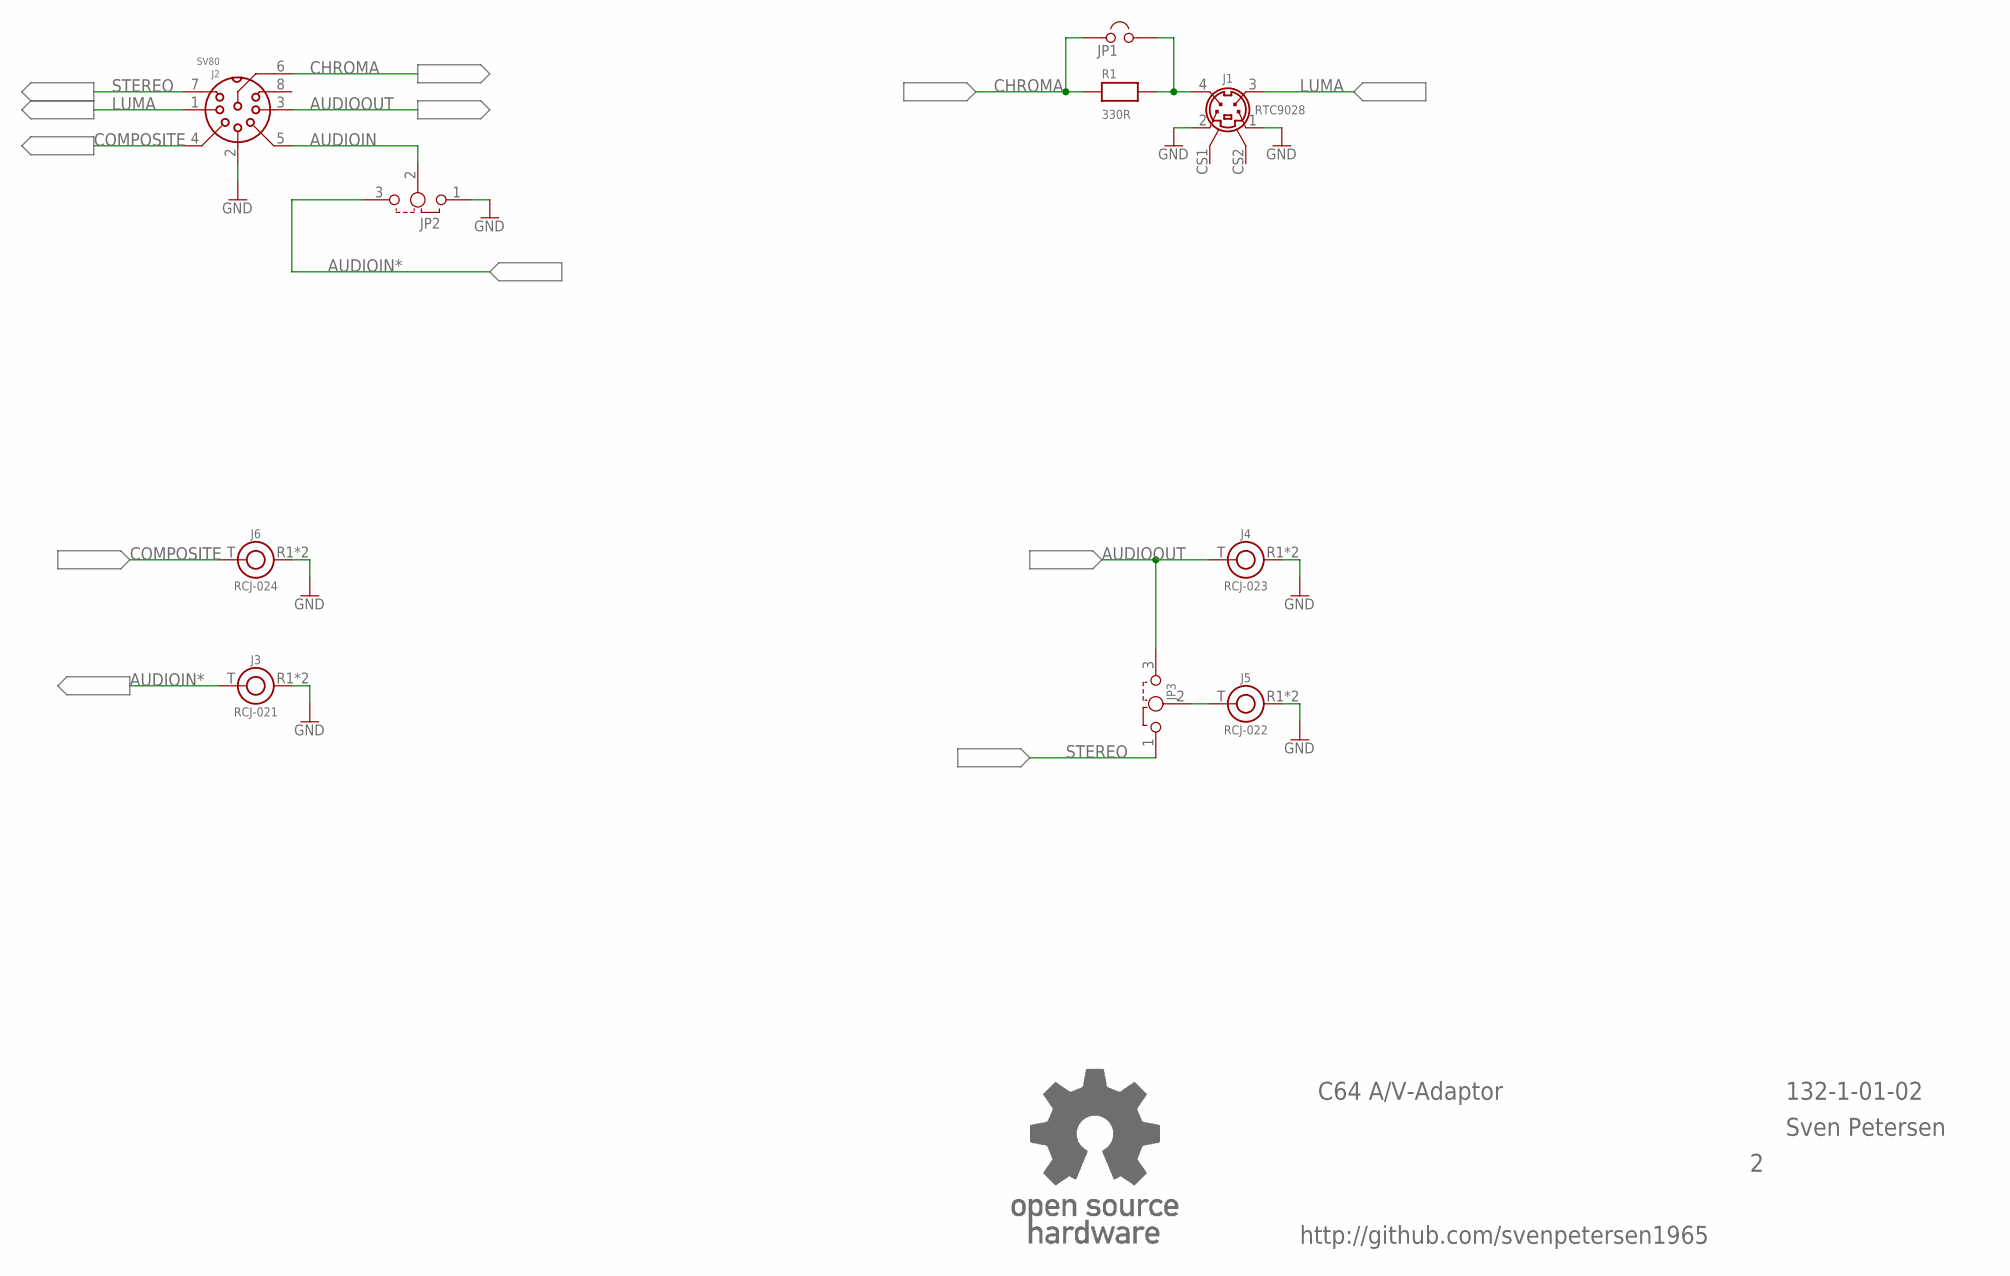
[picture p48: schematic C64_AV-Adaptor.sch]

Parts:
J1: RTC9028; MINIDIN4_V
J2: SV80; SV80_INNER
J3: RCJ-021; RCJ-02X
J4: RCJ-023; RCJ-02X
J5: RCJ-022; RCJ-02X
J6: RCJ-024; RCJ-02X
JP1: JUMPER; 1X02
JP2, JP3: DJUMPER; 1X03
R1: 330R; R-10
U$25: OPEN_SOURCE_HW; OPENHW

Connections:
AUDIOIN: J2.5, JP2.2
AUDIOIN*: J3.T, JP2.3
AUDIOOUT: J2.3, J4.T, JP3.3
AUDIOR: J5.T, JP3.2
CHROMA: J2.6, JP1.1, R1.1
COMPOSITE: J2.4, J6.T
GND: J1.1, J1.2, J2.2, J3.R1 (R), J3.R2 (R), J4.R1 (R), J4.R2 (R), J5.R1 (R), J5.R2 (R), J6.R1 (R), J6.R2 (R), JP2.1
LUMA: J1.3, J2.1
unnamed: J1.4, JP1.2, R1.2
STEREO: J2.7, JP3.1

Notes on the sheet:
C64 A/V-Adaptor
132-1-01-02
Sven Petersen
http://github.com/svenpetersen1965

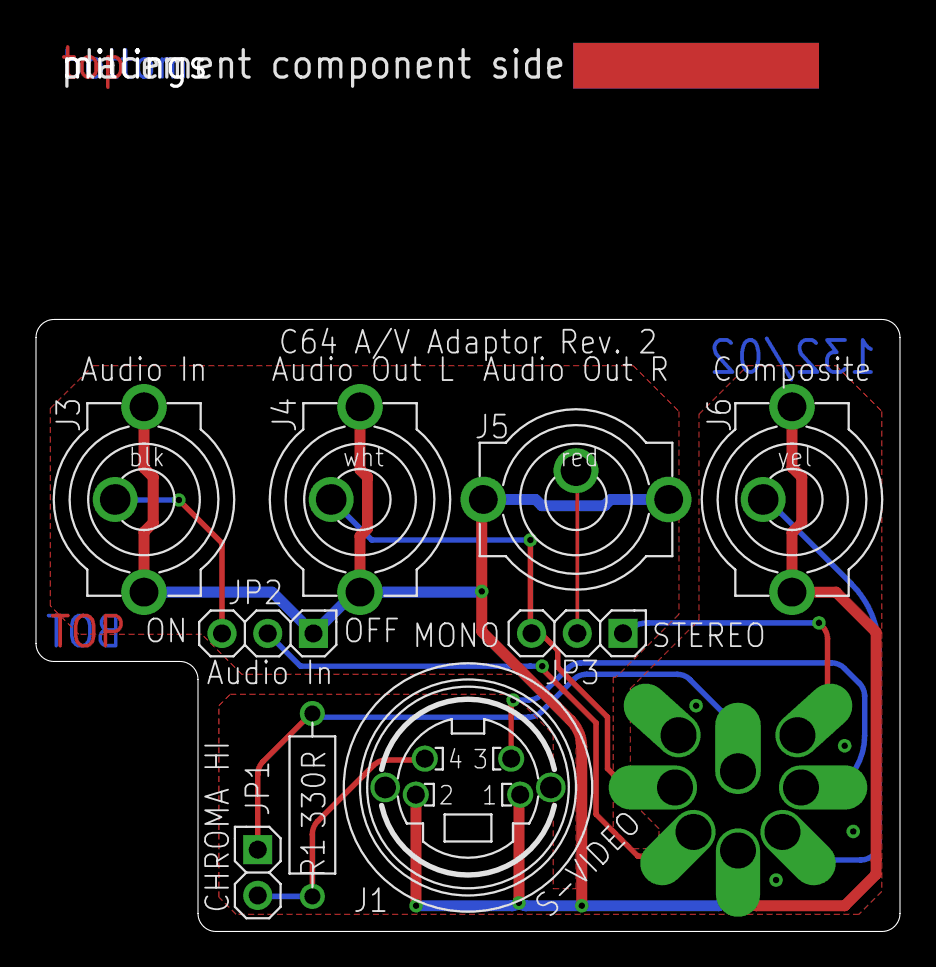
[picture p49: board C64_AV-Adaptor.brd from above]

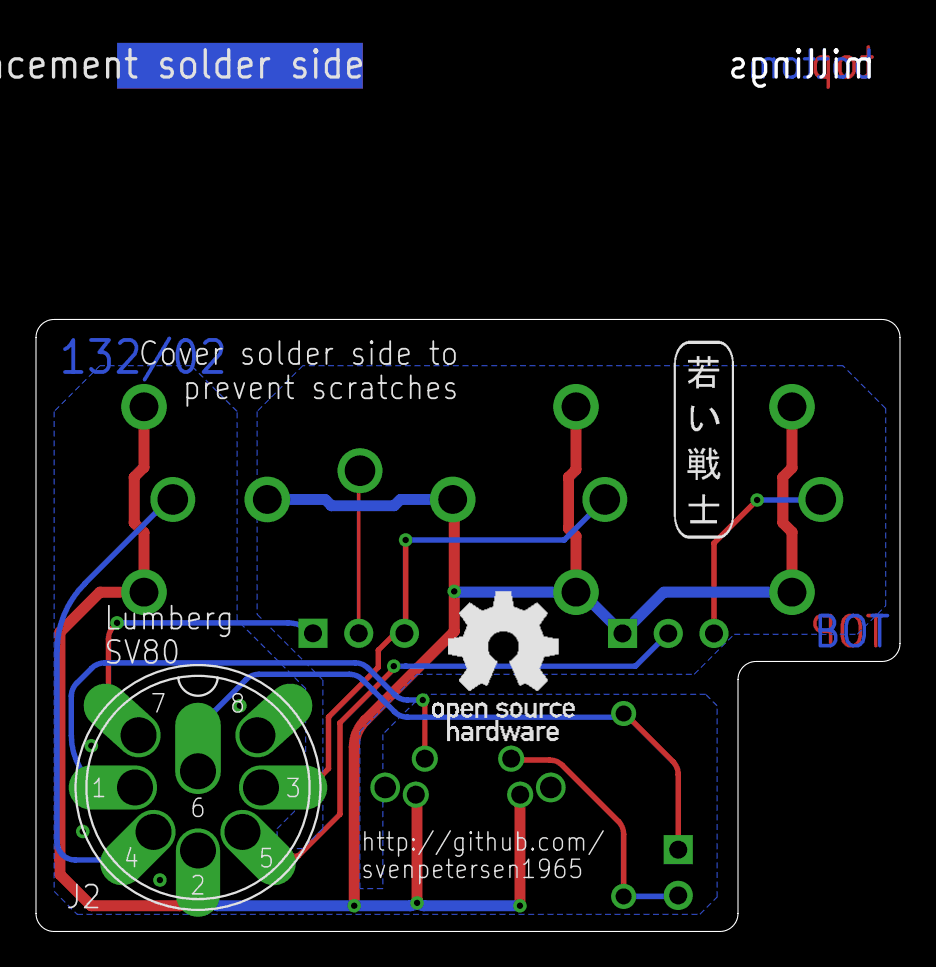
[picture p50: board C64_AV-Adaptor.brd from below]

Board: 2 copper layers, 48.0 x 34.0 mm, 14 parts (3 on the bottom side), 10 nets.

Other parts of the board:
U$22: 2LAYER
U$23: SVEN_TAG
U$24: PCB-TITLE/

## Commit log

2019-10-12 Initial upload
    [C64_AV-Adaptor.brd, C64_AV-Adaptor.sch, C64_AV-Adaptor_bplace_bstop.dxf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]
2019-10-12 Add files via upload
    Library, which contains the footprint of the Lumberg SV 80 insert.
2019-10-21 BOM v0.1 added
    Added a new version of the BOM with jumpers with a latch. This is an improvement in case the 3D printed case is used.
2019-11-09 Versions for ASSY326298 C64 and VIC-20
    New versions, the original C64 8-pin was slightly modified (no bevelling around the RCA jacks for better decals.
    [AV-Adaptor_case v18.f3d, AV-Adaptor_case_5pin v8.f3d, AV-Adaptor_case_VIC-20 v10.f3d]
2019-11-09 Delete top shell.stl
    other naming
    [top shell.stl]
2019-11-09 top shell for regular, ASSY326298 and VIC-20
    New versions added
    [top shell 5 pin.stl, top shell VIC-20.stl, top shell regular.stl]
2020-01-02 Rev. 1 released
    [C64_AV-Adaptor.brd, C64_AV-Adaptor.sch, C64_AV_Adapt_BOM_v1_0.xlsx]
2020-05-26 Added a price calculation
    [C64_AV_Adapt_v1_0_calc.xlsx]
2020-08-10 Silk Screen Update
    [C64_AV-Adaptor.brd, C64_AV-Adaptor.sch]
2022-02-26 Gerbers removed
2022-09-02 Case for PCB Rev. 2
    [AV-Adaptor_case_v2 v3.f3d, C64AV bottom shell v2.stl, C64AV top shell v2.stl]
2022-09-02 PCB Rev. 2 released
    [C64_AV-Adaptor.brd, C64_AV-Adaptor.sch, C64_AV-Adaptor_bottom.dxf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]
2022-09-14 version without header
    Some pcb manufacturer don't get along with my 25 year old header.
    [C64_AV-Adaptor_no_header.brd]
2022-09-14 gerber version without
    For picky pcb manufacturers.
